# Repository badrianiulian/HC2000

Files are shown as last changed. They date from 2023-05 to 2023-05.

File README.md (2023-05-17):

# HC2000

## Note în limba română
Proiect de reconstrucție HC2000

Ce s-a folosit pentru a crea acest proiect:
- Versiunea originală a schemei HC-2000 Rev B care a fost obținută prin intermediul grupului Romanian Home Computer (mulțumiri speciale domnului George Chirtoacă)
- Schema Eagle a HC-2000 Rev B realizată de dl. Liviu Grama, care este de asemenea membru al grupului Romanian Home Computer
- Un exemplar fizic al unui HC-2000 Rev E furnizat de dl. Oică Cezar pentru reparații

Note despre diferențe:
- HC2000_ORIGINAL este proiectul realizat folosind scanările cablajului exemplarului fizic HC-2000 Rev E
- gerberele au fost create folosind proiectul HC2000, care este Rev E modificată pentru a include firele lipite peste cablaj
- observați că unele componente au două valori precum R28, R40 și R41 egale cu 220/1K: prima valoare 220 este pentru Rev B și a doua valoare 1K este pentru Rev E
- unde se întâlnește un "-", înseamnă că acea componentă lipsește pe cablajul Rev E, dar locul de amplasare al componentei este disponibil
- pentru conectorul de alimentare am adăugat pe lângă locul de amplasare al conectorului original, un conector cu 6 pini DIN

**IMPORTANT**: În prima revizie a proiectului s-au strecurat câteva greșeli:
- Nu am observat o tăietură pe placa originală ceea ce a dus la unirea a două trasee. Această secțiune este documentată pe grupul Romanian Home Computer de Radioman V: https://groups.google.com/g/romanianhomecomputer/c/qHbKBThCIQc/m/c_SBp--mCgAJ
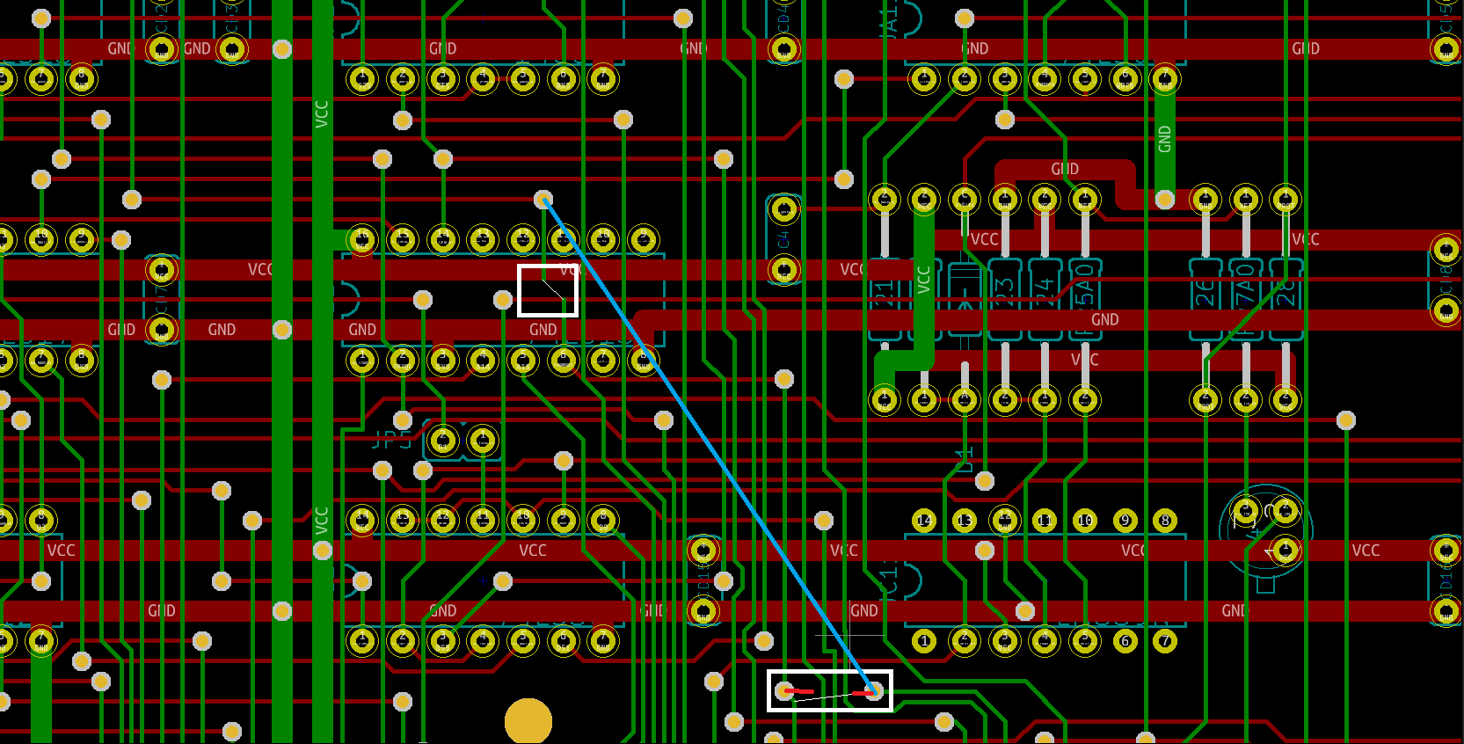
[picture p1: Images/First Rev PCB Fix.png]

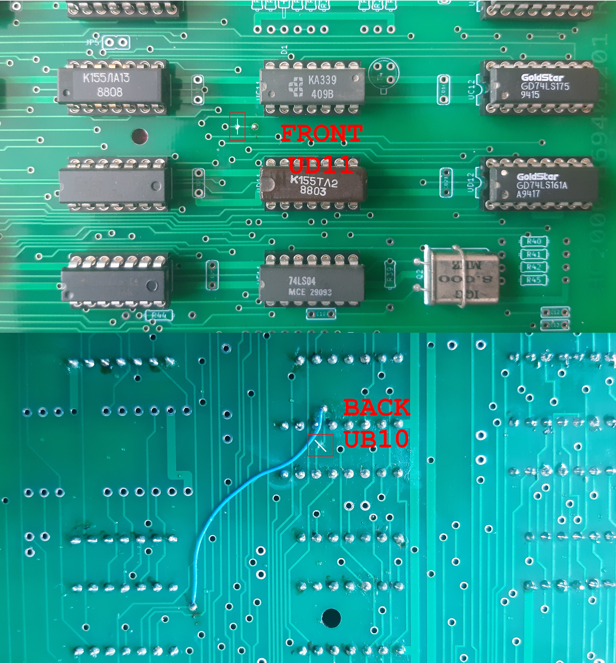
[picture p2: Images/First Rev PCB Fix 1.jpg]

- Au rămas două circuite cu titulatura veche de pe proiectul original care a fost convertit
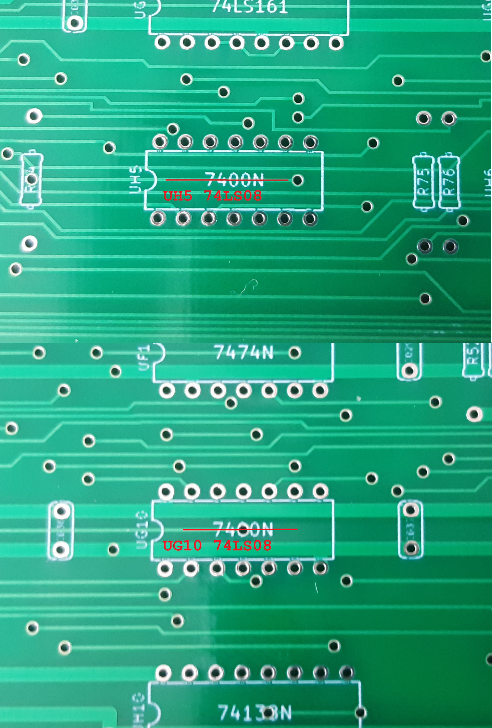
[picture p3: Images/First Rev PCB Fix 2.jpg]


## English notes
HC2000 rebuild project

What was used to create this project:
- Original version of the schematic of HC-2000 Rev B that was obtained through the Romanian Home Computer group (special thanks to mr. George Chirtoacă)
- Eagle schematic of the HC-2000 Rev B made by mr. Liviu Grama also a member of the Romanian Home Computer group
- A physical HC-2000 Rev E provided by mr. Oică Cezar for repairs

Notes on the diferences:
- HC2000_ORIGINAL is the project made using PCB scans of the physical HC-2000 Rev E
- gerbers were created using HC2000 project witch is the modified Rev E witch includes the over-the-PCB soldered wires
- notice some components have two values like R28, R40 and R41 equal 220/1K: first value 220 is for Rev B and second value 1K is for Rev E
- where a "-" is encountered, it means that the component is missing on Rev E but the footprint is available
- for the power connector I added side by side with the original connector's footprint, a 6-pin DIN connector

**IMPORTANT**: In the original project a few mistakes slipped in.
- I did not notice a cut on the original PCB witch led to joining of two tracks. This section is documented on the Romanian Home Computer group by Radioman V: https://groups.google.com/g/romanianhomecomputer/c/qHbKBThCIQc/m/c_SBp--mCgAJ


- Two circuits retained the old names from the original converted project


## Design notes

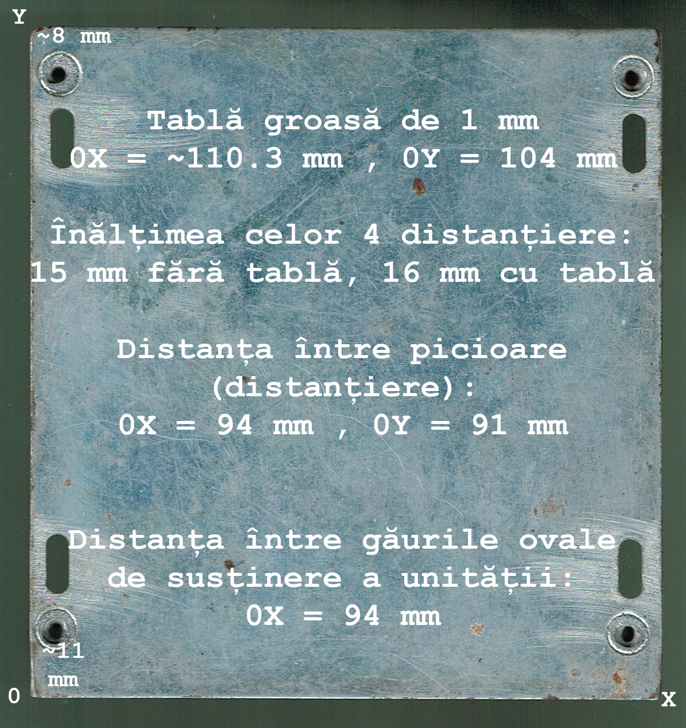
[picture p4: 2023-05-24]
Other/Floppy_Stand.jpg

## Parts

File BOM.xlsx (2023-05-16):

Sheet: ListaOriginală
Collated Components:
Item | Qty | Reference(s) | Value | LibPart | Footprint | Datasheet | DNP | Sim.Device | Sim.Pins
1 | 2 | C1, C3 | 100n | HC2000:C-EU025-025X050 | HC2000:C025-030X050
2 | 1 | C2 | 4n7 | HC2000:C-EU025-030X050 | HC2000:C025-030X050
3 | 1 | C4 | 3,3uF/4,7uF | HC2000:CPOL-EU140CLH-0810 | HC2000:C025-024X044
4 | 1 | C5 | 270p | HC2000:C-EU025-030X050 | HC2000:C025-030X050
5 | 1 | C6 | 150p | HC2000:C-EU025-025X050 | HC2000:C025-030X050
6 | 1 | C7 | 10p/15p | HC2000:C-EU025-025X050 | HC2000:C025-030X050
7 | 1 | C8 | 220p/- | HC2000:C-EU025-025X050 | HC2000:C025-030X050
8 | 1 | C9 | 220p | HC2000:C-EU025-025X050 | HC2000:C025-030X050
9 | 1 | C10 | 270p | HC2000:C-EU025-024X044 | HC2000:C025-025X050
10 | 1 | C11 | 270p | HC2000:C-EU025-030X050 | HC2000:C025-025X050
11 | 4 | C12, C13, C16, C17 | 4n7 | HC2000:C-EU025-025X050 | HC2000:C025-025X050
12 | 1 | C14 | 100p/180p | HC2000:C-EU025-025X050 | HC2000:C025-030X050
13 | 1 | C15 | 10u | HC2000:CPOL-EU140CLH-1010 | HC2000:C025-024X024
14 | 7 | CD1, CD6, CD22, CD36, CD37, CD39, CD40 | u1 | :C-EU025-024X044_4 | HC2000:C025-024X044
15 | 5 | CD2, CD4, CD7, CD8, CD38 | - | :C-EU025-024X044_4 | HC2000:C025-024X044
16 | 2 | CD3, CD5 | 100u | :C-EU025-024X044_4 | HC2000:C025-024X044
17 | 1 | CD9 | u1 | :C-EU025-024X044_10 | HC2000:C025-024X044
18 | 1 | CD10 | - | :C-EU025-024X044_11 | HC2000:C025-024X044
19 | 1 | CD11 | u1 | :C-EU025-024X044_11 | HC2000:C025-024X044
20 | 1 | CD12 | 100u | :C-EU025-024X044_12 | HC2000:C025-024X044
21 | 1 | CD13 | u1 | :C-EU025-024X044_15 | HC2000:C025-024X044
22 | 1 | CD14 | - | :C-EU025-024X044_14 | HC2000:C025-024X044
23 | 1 | CD15 | u1 | :C-EU025-024X044_16 | HC2000:C025-024X044
24 | 9 | CD16, CD17, CD24, CD25, CD26, CD27, CD31, CD32, CD33 | u1 | :C-EU025-024X044_13 | HC2000:C025-024X044
25 | 1 | CD18 | 100u | :C-EU025-024X044_13 | HC2000:C025-024X044
26 | 1 | CD19 | u1 | HC2000:C-EU025-024X044 | HC2000:C025-024X044
27 | 1 | CD20 | u1 | :C-EU025-024X044_17 | HC2000:C025-024X044
28 | 1 | CD21 | u1 | :C-EU025-024X044_5 | HC2000:C025-024X044
29 | 1 | CD23 | 100u | :C-EU025-024X044_8 | HC2000:C025-024X044
30 | 1 | CD28 | - | :C-EU025-024X044_1 | HC2000:C025-024X044
31 | 1 | CD29 | - | :C-EU025-024X044_3 | HC2000:C025-024X044
32 | 1 | CD30 | u1 | :C-EU025-024X044_2 | HC2000:C025-024X044
33 | 1 | CD34 | - | :C-EU025-024X044_13 | HC2000:C025-024X044
34 | 1 | CD35 | u1 | :C-EU025-024X044_6 | HC2000:C025-024X044
35 | 1 | CT0 | 10-60pF | HC2000:C-TRIMM808 | HC2000:CTRIM808-BC
36 | 1 | CX0 | 100u | HC2000:CPOL-EU140CLH-0810 | HC2000:C025-024X044
37 | 1 | CY1 | 1.5u | HC2000:CPOL-EU140CLH-1010 | HC2000:140CLH-1010
38 | 8 | D1, D2, D3, D4, D5, D6, D7, D8 | 1N4148 | HC2000:1N4148DO35-10 | HC2000:DO35-10
39 | 1 | DX1 | 1N4148 | HC2000:1N4148DO35-7 | HC2000:DO35-7 | https://assets.nexperia.com/documents/data-sheet/1N4148_1N4448.pdf |  | D | 1=K 2=A
40 | 1 | J1 | VIDEO | HC2000:F09FD | HC2000:DSUB-9_Female_Horizontal_P2.77x2.84mm_EdgePinOffset7.70mm_Housed_MountingHolesOffset9.12mm
41 | 1 | J2 | JOYSTICK | HC2000:F09MD | HC2000:DSUB-9_Male_Horizontal_P2.77x2.84mm_EdgePinOffset7.70mm_Housed_MountingHolesOffset9.12mm
42 | 1 | J3 | MAB5SH | HC2000:MAB5SH | HC2000:MAB5SH
43 | 2 | J4, J6 | . | HC2000:HC-POWER | HC2000:HC-POWER
44 | 1 | J5 | RS232 + RETEA | HC2000:F09FD | HC2000:DSUB-9_Female_Horizontal_P2.77x2.84mm_EdgePinOffset7.70mm_Housed_MountingHolesOffset9.12mm
45 | 2 | J7, J8 | FDD-CON | HC2000:PINHD-2X17 | HC2000:2X17
46 | 1 | J9 | . | HC2000:MTA04-100 | HC2000:10X04MTA
47 | 1 | J10 | SDS-60J | HC2000:SDS-60J | HC2000:SDS-60J-CUI_SDS-60J
48 | 2 | JP2, JP5 | - | HC2000:JP1E | HC2000:JP1
49 | 1 | KB-CONN0 | DIP16 | HC2000:DIL16 | HC2000:DIL16
50 | 1 | L1 | 100 | HC2000:L-USPIS2816 | HC2000:PIS2816
51 | 1 | Q1 | 17,734 | HC2000:CRYSTALHC18U-H | HC2000:HC18U-H
52 | 1 | Q2 | 8MHz | HC2000:CRYSTALHC18U-H | HC2000:HC18U-H
53 | 24 | R1, R2, R3, R4, R13, R14, R34, R37, R38, R44, R47, R49, R51, R53, R55, R58, R63, R72, R73, R74, R75, R76, R77, R78 | 1k | HC2000:R-EU_0204{slash}7 | HC2000:0204_7
54 | 2 | R5, R60 | 330/300 | HC2000:R-EU_0204{slash}7 | HC2000:0204_7
55 | 1 | R6 | 2M2/2M | HC2000:R-EU_0204{slash}7 | HC2000:0204_7
56 | 11 | R7, R8, R9, R11, R15, R16, R18, R20, R25A0, R29, R52 | 10k | HC2000:R-EU_0204{slash}7 | HC2000:0204_7
57 | 1 | R10 | 47k | HC2000:R-EU_0204{slash}7 | HC2000:0204_7
58 | 2 | R12, R17 | 2k | HC2000:R-EU_0204{slash}7 | HC2000:0204_7
59 | 5 | R19, R19B0, R33, R43, R50A0 | 470 | HC2000:R-EU_0204{slash}7 | HC2000:0204_7
60 | 1 | R21 | 10k/470k | HC2000:R-EU_0204{slash}7 | HC2000:0204_7
61 | 1 | R22 | 8k2/6k | HC2000:R-EU_0204{slash}7 | HC2000:0204_7
62 | 1 | R23 | 220 | HC2000:R-EU_0204{slash}7 | HC2000:0204_7
63 | 1 | R24 | 430 | HC2000:R-EU_0204{slash}7 | HC2000:0204_7
64 | 3 | R26, R42, R45 | 330/- | HC2000:R-EU_0204{slash}7 | HC2000:0204_7
65 | 1 | R27A0 | 47 | HC2000:R-EU_0204{slash}7 | HC2000:0204_7
66 | 4 | R28, R40, R41, R56 | 220/1k | HC2000:R-EU_0204{slash}7 | HC2000:0204_7
67 | 2 | R30, R48 | 75/69 | HC2000:R-EU_0204{slash}7 | HC2000:0204_7
68 | 1 | R31 | 240/270 | HC2000:R-EU_0204{slash}7 | HC2000:0204_7
69 | 1 | R32 | 1k5 | HC2000:R-EU_0204{slash}7 | HC2000:0204_7
70 | 1 | R35 | 680 | HC2000:R-EU_0204{slash}7 | HC2000:0204_7
71 | 1 | R36 | 100 | HC2000:R-EU_0204{slash}7 | HC2000:0204_7
72 | 3 | R39, R46, R57 | 560 | HC2000:R-EU_0204{slash}7 | HC2000:0204_7
73 | 2 | R54, R61 | 3k9 | HC2000:R-EU_0204{slash}7 | HC2000:0204_7
74 | 1 | R59 | 27k | HC2000:R-EU_0204{slash}7 | HC2000:0204_7
75 | 2 | R62, R67 | 910 | HC2000:R-EU_0204{slash}7 | HC2000:0204_7
76 | 1 | R64 | 7k5 | HC2000:R-EU_0204{slash}7 | HC2000:0204_7
77 | 2 | R65, R71 | 510 | HC2000:R-EU_0204{slash}7 | HC2000:0204_7
78 | 1 | R66 | 1k8/1k6 | HC2000:R-EU_0204{slash}7 | HC2000:0204_7
79 | 1 | R68 | 5k6/5k1 | HC2000:R-EU_0204{slash}7 | HC2000:0204_7
80 | 1 | R69 | 2k7 | HC2000:R-EU_0204{slash}7 | HC2000:0204_7
81 | 1 | R70 | 1k1 | HC2000:R-EU_0204{slash}7 | HC2000:0204_7
82 | 1 | RP1 | 10k | HC2000:G08R | HC2000:SIL9
83 | 1 | SPEAKER0 | BEL | HC2000:AL11P | HC2000:AL11P
84 | 1 | SW1 | RESET_SW | HC2000:RESET_SW | HC2000:RESET_SW | ~
85 | 1 | T1 | BD139 | HC2000:BD139 | HC2000:TO-126-3_Vertical
86 | 1 | T2 | 2N2369/2N2368 | HC2000:2N2369 | HC2000:TO18
87 | 1 | T3 | 2N2369/BC108A | HC2000:2N2369 | HC2000:TO18
88 | 2 | T4, T5 | BC177 | HC2000:BC177 | HC2000:TO18
89 | 2 | UA1, UC7 | 74244N | HC2000:74244N | HC2000:DIL20
90 | 1 | UA7 | LM324N | HC2000:LM324N | HC2000:DIL14
91 | 2 | UA8, UC8 | 2k x 4bit/- | HC2000:2114 | HC2000:DIL18
92 | 5 | UA9, UB10, UE4, UF8, UH10 | 74138N | HC2000:74138N | HC2000:DIL16
93 | 1 | UA10 | 1488 | HC2000:DIL14 | HC2000:DIL14
94 | 1 | UA11 | 7406N | HC2000:7406N | HC2000:DIL14
95 | 1 | UA12 | NE555 | HC2000:NE555 | HC2000:DIL-08
96 | 2 | UA23, UA34 | 7409N | HC2000:7409N | HC2000:DIL14
97 | 8 | UB1, UD3, UD10, UE10, UF4, UF10, UG12, UH12 | 7474N | HC2000:7474N | HC2000:DIL14
98 | 4 | UB2, UG10, UH3, UH5 | 7400N | HC2000:7400N | HC2000:DIL14
99 | 1 | UB3 | 74367N | HC2000:74367N | HC2000:DIL16
100 | 1 | UB6 | 27C256/27C512 | HC2000:27256 | HC2000:DIL28
101 | 2 | UB9, UF7 | 74174N | HC2000:74174N | HC2000:DIL16
102 | 1 | UB12 | 74153N | HC2000:74153N | HC2000:DIL16
103 | 1 | UB45 | Z80 - CPU | HC2000:Z80CPU | HC2000:DIL40
104 | 4 | UC1, UE11, UG0, UG4 | 7404N | HC2000:7404N | HC2000:DIL14
105 | 1 | UC2 | 7427N | HC2000:7427N | HC2000:DIL14
106 | 5 | UC3, UE3, UF9, UG9, UH8 | 7432N | HC2000:7432N | HC2000:DIL14
107 | 5 | UC4, UC5, UD5, UG7, UH6 | 74257N | HC2000:74257N | HC2000:DIL16
108 | 1 | UC6 | 74373N | HC2000:74373N | HC2000:DIL20
109 | 1 | UC9 | 74125N | HC2000:74125N | HC2000:DIL14
110 | 1 | UC10 | 74LS38N | HC2000:7403N | HC2000:DIL14
111 | 1 | UC11 | LM339N | HC2000:LM339N | HC2000:DIL14
112 | 4 | UC12, UF3, UG3, UH1 | 74175N | HC2000:74175N | HC2000:DIL16
113 | 3 | UD1, UE2, UG11 | 7408N | HC2000:7408N | HC2000:DIL14
114 | 1 | UD4 | 74157N | HC2000:74157N | HC2000:DIL16
115 | 3 | UD6, UF6, UG6 | 74374N | HC2000:74374N | HC2000:DIL20
116 | 2 | UD7, UE7 | 41464 | HC2000:41464C | HC2000:DIL18
117 | 1 | UD11 | 7414N | HC2000:7414N | HC2000:DIL14
118 | 1 | UD12 | 74LS161N | HC2000:4161P | HC2000:DIL16
119 | 5 | UE5, UF2, UF5, UG5, UH7 | 74LS161 | HC2000:4161P | HC2000:DIL16
120 | 1 | UE6 | 74166N | HC2000:74166N | HC2000:DIL16
121 | 1 | UE8 | 8272 | HC2000:8272 | HC2000:DIL40
122 | 1 | UE8A0 | 27128P/- | HC2000:27128P | HC2000:DIL28-6
123 | 1 | UF12 | 1489 | HC2000:DIL14 | HC2000:DIL14
124 | 1 | UG1 | 7442N | HC2000:7442N | HC2000:DIL16
125 | 1 | UG2 | 82S128 | HC2000:DIL16 | HC2000:DIL16
126 | 1 | UG8 | 7405N | HC2000:7405N | HC2000:DIL14
127 | 1 | UGX1 | PROM ALT - W27C256-45 | HC2000:27256 | HC2000:DIL28
128 | 1 | UH4 | 7486N | HC2000:7486N | HC2000:DIL14
129 | 1 | UH11 | 7493N | HC2000:7493N | HC2000:DIL14
130 | 1 | UX1 | UM6116-3 | HC2000:6116 | HC2000:DIL24
131 | 1 | UX2 | LM555M | HC2000:LM555M | HC2000:DIL14
132 | 1 | Z1 | HCBUS | HC2000:HCBUS | HC2000:HC_Bus_Edge_Connector

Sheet: Mărunțișuri
Collated Components:
Item | Qty | Reference(s) | Value | LibPart | Footprint | Datasheet | DNP | Sim.Device | Sim.Pins
1 | 2 | C1, C3 | 100n | HC2000:C-EU025-025X050 | HC2000:C025-030X050
2 | 1 | C2 | 4n7 | HC2000:C-EU025-030X050 | HC2000:C025-030X050
3 | 1 | C4 | 3,3uF/4,7uF | HC2000:CPOL-EU140CLH-0810 | HC2000:C025-024X044
4 | 1 | C5 | 270p | HC2000:C-EU025-030X050 | HC2000:C025-030X050
5 | 1 | C6 | 150p | HC2000:C-EU025-025X050 | HC2000:C025-030X050
6 | 1 | C7 | 10p/15p | HC2000:C-EU025-025X050 | HC2000:C025-030X050
7 | 1 | C8 | 220p/- | HC2000:C-EU025-025X050 | HC2000:C025-030X050
8 | 1 | C9 | 220p | HC2000:C-EU025-025X050 | HC2000:C025-030X050
9 | 1 | C10 | 270p | HC2000:C-EU025-024X044 | HC2000:C025-025X050
10 | 1 | C11 | 270p | HC2000:C-EU025-030X050 | HC2000:C025-025X050
11 | 4 | C12, C13, C16, C17 | 4n7 | HC2000:C-EU025-025X050 | HC2000:C025-025X050
12 | 1 | C14 | 100p/180p | HC2000:C-EU025-025X050 | HC2000:C025-030X050
13 | 1 | C15 | 10u | HC2000:CPOL-EU140CLH-1010 | HC2000:C025-024X024
14 | 7 | CD1, CD6, CD22, CD36, CD37, CD39, CD40 | u1 | :C-EU025-024X044_4 | HC2000:C025-024X044
15 | 5 | CD2, CD4, CD7, CD8, CD38 | - | :C-EU025-024X044_4 | HC2000:C025-024X044
16 | 2 | CD3, CD5 | 100u | :C-EU025-024X044_4 | HC2000:C025-024X044
17 | 1 | CD9 | u1 | :C-EU025-024X044_10 | HC2000:C025-024X044
18 | 1 | CD10 | - | :C-EU025-024X044_11 | HC2000:C025-024X044
19 | 1 | CD11 | u1 | :C-EU025-024X044_11 | HC2000:C025-024X044
20 | 1 | CD12 | 100u | :C-EU025-024X044_12 | HC2000:C025-024X044
21 | 1 | CD13 | u1 | :C-EU025-024X044_15 | HC2000:C025-024X044
22 | 1 | CD14 | - | :C-EU025-024X044_14 | HC2000:C025-024X044
23 | 1 | CD15 | u1 | :C-EU025-024X044_16 | HC2000:C025-024X044
24 | 9 | CD16, CD17, CD24, CD25, CD26, CD27, CD31, CD32, CD33 | u1 | :C-EU025-024X044_13 | HC2000:C025-024X044
25 | 1 | CD18 | 100u | :C-EU025-024X044_13 | HC2000:C025-024X044
26 | 1 | CD19 | u1 | HC2000:C-EU025-024X044 | HC2000:C025-024X044
27 | 1 | CD20 | u1 | :C-EU025-024X044_17 | HC2000:C025-024X044
28 | 1 | CD21 | u1 | :C-EU025-024X044_5 | HC2000:C025-024X044
29 | 1 | CD23 | 100u | :C-EU025-024X044_8 | HC2000:C025-024X044
30 | 1 | CD28 | - | :C-EU025-024X044_1 | HC2000:C025-024X044
31 | 1 | CD29 | - | :C-EU025-024X044_3 | HC2000:C025-024X044
32 | 1 | CD30 | u1 | :C-EU025-024X044_2 | HC2000:C025-024X044
33 | 1 | CD34 | - | :C-EU025-024X044_13 | HC2000:C025-024X044
34 | 1 | CD35 | u1 | :C-EU025-024X044_6 | HC2000:C025-024X044
35 | 1 | CT0 | 10-60pF | HC2000:C-TRIMM808 | HC2000:CTRIM808-BC
36 | 1 | CX0 | 100u | HC2000:CPOL-EU140CLH-0810 | HC2000:C025-024X044
37 | 1 | CY1 | 1.5u | HC2000:CPOL-EU140CLH-1010 | HC2000:140CLH-1010
38 | 8 | D1, D2, D3, D4, D5, D6, D7, D8 | 1N4148 | HC2000:1N4148DO35-10 | HC2000:DO35-10
39 | 1 | DX1 | 1N4148 | HC2000:1N4148DO35-7 | HC2000:DO35-7 | https://assets.nexperia.com/documents/data-sheet/1N4148_1N4448.pdf |  | D | 1=K 2=A
40 | 1 | J1 | VIDEO | HC2000:F09FD | HC2000:DSUB-9_Female_Horizontal_P2.77x2.84mm_EdgePinOffset7.70mm_Housed_MountingHolesOffset9.12mm
41 | 1 | J2 | JOYSTICK | HC2000:F09MD | HC2000:DSUB-9_Male_Horizontal_P2.77x2.84mm_EdgePinOffset7.70mm_Housed_MountingHolesOffset9.12mm
42 | 1 | J3 | MAB5SH | HC2000:MAB5SH | HC2000:MAB5SH
43 | 2 | J4, J6 | . | HC2000:HC-POWER | HC2000:HC-POWER
44 | 1 | J5 | RS232 + RETEA | HC2000:F09FD | HC2000:DSUB-9_Female_Horizontal_P2.77x2.84mm_EdgePinOffset7.70mm_Housed_MountingHolesOffset9.12mm
45 | 2 | J7, J8 | FDD-CON | HC2000:PINHD-2X17 | HC2000:2X17
46 | 1 | J9 | . | HC2000:MTA04-100 | HC2000:10X04MTA
47 | 1 | J10 | SDS-60J | HC2000:SDS-60J | HC2000:SDS-60J-CUI_SDS-60J
48 | 2 | JP2, JP5 | - | HC2000:JP1E | HC2000:JP1
49 | 1 | KB-CONN0 | DIP16 | HC2000:DIL16 | HC2000:DIL16
50 | 1 | L1 | 100 | HC2000:L-USPIS2816 | HC2000:PIS2816
51 | 1 | Q1 | 17,734 | HC2000:CRYSTALHC18U-H | HC2000:HC18U-H
52 | 1 | Q2 | 8MHz | HC2000:CRYSTALHC18U-H | HC2000:HC18U-H
53 | 24 | R1, R2, R3, R4, R13, R14, R34, R37, R38, R44, R47, R49, R51, R53, R55, R58, R63, R72, R73, R74, R75, R76, R77, R78 | 1k | HC2000:R-EU_0204{slash}7 | HC2000:0204_7
54 | 2 | R5, R60 | 330/300 | HC2000:R-EU_0204{slash}7 | HC2000:0204_7
55 | 1 | R6 | 2M2/2M | HC2000:R-EU_0204{slash}7 | HC2000:0204_7
56 | 11 | R7, R8, R9, R11, R15, R16, R18, R20, R25A0, R29, R52 | 10k | HC2000:R-EU_0204{slash}7 | HC2000:0204_7
57 | 1 | R10 | 47k | HC2000:R-EU_0204{slash}7 | HC2000:0204_7
58 | 2 | R12, R17 | 2k | HC2000:R-EU_0204{slash}7 | HC2000:0204_7
59 | 5 | R19, R19B0, R33, R43, R50A0 | 470 | HC2000:R-EU_0204{slash}7 | HC2000:0204_7
60 | 1 | R21 | 10k/470k | HC2000:R-EU_0204{slash}7 | HC2000:0204_7
61 | 1 | R22 | 8k2/6k | HC2000:R-EU_0204{slash}7 | HC2000:0204_7
62 | 1 | R23 | 220 | HC2000:R-EU_0204{slash}7 | HC2000:0204_7
63 | 1 | R24 | 430 | HC2000:R-EU_0204{slash}7 | HC2000:0204_7
64 | 3 | R26, R42, R45 | 330/- | HC2000:R-EU_0204{slash}7 | HC2000:0204_7
65 | 1 | R27A0 | 47 | HC2000:R-EU_0204{slash}7 | HC2000:0204_7
66 | 4 | R28, R40, R41, R56 | 220/1k | HC2000:R-EU_0204{slash}7 | HC2000:0204_7
67 | 2 | R30, R48 | 75/69 | HC2000:R-EU_0204{slash}7 | HC2000:0204_7
68 | 1 | R31 | 240/270 | HC2000:R-EU_0204{slash}7 | HC2000:0204_7
69 | 1 | R32 | 1k5 | HC2000:R-EU_0204{slash}7 | HC2000:0204_7
70 | 1 | R35 | 680 | HC2000:R-EU_0204{slash}7 | HC2000:0204_7
71 | 1 | R36 | 100 | HC2000:R-EU_0204{slash}7 | HC2000:0204_7
72 | 3 | R39, R46, R57 | 560 | HC2000:R-EU_0204{slash}7 | HC2000:0204_7
73 | 2 | R54, R61 | 3k9 | HC2000:R-EU_0204{slash}7 | HC2000:0204_7
74 | 1 | R59 | 27k | HC2000:R-EU_0204{slash}7 | HC2000:0204_7
75 | 2 | R62, R67 | 910 | HC2000:R-EU_0204{slash}7 | HC2000:0204_7
76 | 1 | R64 | 7k5 | HC2000:R-EU_0204{slash}7 | HC2000:0204_7
77 | 2 | R65, R71 | 510 | HC2000:R-EU_0204{slash}7 | HC2000:0204_7
78 | 1 | R66 | 1k8/1k6 | HC2000:R-EU_0204{slash}7 | HC2000:0204_7
79 | 1 | R68 | 5k6/5k1 | HC2000:R-EU_0204{slash}7 | HC2000:0204_7
80 | 1 | R69 | 2k7 | HC2000:R-EU_0204{slash}7 | HC2000:0204_7
81 | 1 | R70 | 1k1 | HC2000:R-EU_0204{slash}7 | HC2000:0204_7
82 | 1 | RP1 | 10k | HC2000:G08R | HC2000:SIL9
83 | 1 | SPEAKER0 | BEL | HC2000:AL11P | HC2000:AL11P
84 | 1 | SW1 | RESET_SW | HC2000:RESET_SW | HC2000:RESET_SW | ~

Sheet: Tranzistoare
Collated Components:
Item | Qty | Reference(s) | Value | LibPart | Footprint | Datasheet | DNP | Sim.Device | Sim.Pins
85 | 1 | T1 | BD139 | HC2000:BD139 | HC2000:TO-126-3_Vertical
86 | 1 | T2 | 2N2369/2N2368 | HC2000:2N2369 | HC2000:TO18
87 | 1 | T3 | 2N2369/BC108A | HC2000:2N2369 | HC2000:TO18
88 | 2 | T4, T5 | BC177 | HC2000:BC177 | HC2000:TO18

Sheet: Circuite
Collated Components:
Item | Qty | Reference(s) | Value | Qty | Reference(s) | Rev E |  | LibPart | Footprint | Datasheet | DNP | Sim.Device | Sim.Pins
93 | 1 | UA10 | 1488 | 1 | UA10 | 1488 |  | HC2000:DIL14 | HC2000:DIL14
123 | 1 | UF12 | 1489 | 1 | UF12 | 1489 |  | HC2000:DIL14 | HC2000:DIL14
100 | 1 | UB6 | 27C512 | 1 | UB6 | 27C512 | Am W27C512-70 care ar trebui să meargă | HC2000:27256 | HC2000:DIL28
98 | 2 | UB2, UH3 | 7400N | 2 | UB2, UH3 | 74LS00 |  | HC2000:7400N | HC2000:DIL14
104 | 4 | UC1, UE11, UG0, UG4 | 7404N | 4 | UC1, UE11, UG0, UG4 | 74LS04 | Merg Beta 7404? Am mai multe | HC2000:7404N | HC2000:DIL14
126 | 1 | UG8 | 7405N | 1 | UG8 | 74LS05 = К555ЛН2 |  | HC2000:7405N | HC2000:DIL14
94 | 1 | UA11 | 7406N | 1 | UA11 | 74LS06 |  | HC2000:7406N | HC2000:DIL14
113 | 5 | UD1, UE2, UG10, UG11, UH5 | 7408N | 5 | UD1, UE2, UG10, UG11, UH5 | 74LS08 |  | HC2000:7408N | HC2000:DIL14
96 | 2 | UA23, UA34 | 7409N | 2 | UA23, UA34 | 74LS09 |  | HC2000:7409N | HC2000:DIL14
109 | 1 | UC9 | 74125N | 1 | UC9 | 74LS125A |  | HC2000:74125N | HC2000:DIL14
92 | 5 | UA9, UB10, UE4, UF8, UH10 | 74138N | 5 | UA9, UB10, UE4, UF8, UH10 | 74LS138 |  | HC2000:74138N | HC2000:DIL16
117 | 1 | UD11 | 7414N | 1 | UD11 | 74LS14 = К155ТЛ2 |  | HC2000:7414N | HC2000:DIL14
102 | 1 | UB12 | 74153N | 1 | UB12 | 74LS153 |  | HC2000:74153N | HC2000:DIL16
114 | 1 | UD4 | 74157N | 1 | UD4 | 74LS157 |  | HC2000:74157N | HC2000:DIL16
119 | 6 | UD12, UE5, UF2, UF5, UG5, UH7 | 74LS161 | 6 | UD12, UE5, UF2, UF5, UG5, UH7 | 74LS161A |  | HC2000:4161P | HC2000:DIL16
120 | 1 | UE6 | 74166N | 1 | UE6 | 74LS166 |  | HC2000:74166N | HC2000:DIL16
101 | 2 | UB9, UF7 | 74174N | 2 | UB9, UF7 | 74LS174 = К555ТМ9 |  | HC2000:74174N | HC2000:DIL16
112 | 4 | UC12, UF3, UG3, UH1 | 74175N | 4 | UC12, UF3, UG3, UH1 | 74LS175 |  | HC2000:74175N | HC2000:DIL16
89 | 2 | UA1, UC7 | 74244N | 2 | UA1, UC7 | 74LS244 = К1533АП5 |  | HC2000:74244N | HC2000:DIL20
107 | 5 | UC4, UC5, UD5, UG7, UH6 | 74257N | 5 | UC4, UC5, UD5, UG7, UH6 | 74LS257A |  | HC2000:74257N | HC2000:DIL16
105 | 1 | UC2 | 7427N | 1 | UC2 | 74LS27 |  | HC2000:7427N | HC2000:DIL14
106 | 5 | UC3, UE3, UF9, UG9, UH8 | 7432N | 5 | UC3, UE3, UF9, UG9, UH8 | 74LS32 |  | HC2000:7432N | HC2000:DIL14
99 | 1 | UB3 | 74367N | 1 | UB3 | 74LS367AN |  | HC2000:74367N | HC2000:DIL16
108 | 1 | UC6 | 74373N | 1 | UC6 | 74LS373 |  | HC2000:74373N | HC2000:DIL20
115 | 3 | UD6, UF6, UG6 | 74374N | 3 | UD6, UF6, UG6 | 74LS374B1 |  | HC2000:74374N | HC2000:DIL20
110 | 1 | UC10 | 74LS38N | 1 | UC10 | 74LS38N | Am | HC2000:7403N | HC2000:DIL14
124 | 1 | UG1 | 7442N | 1 | UG1 | 74LS442 |  | HC2000:7442N | HC2000:DIL16
97 | 8 | UB1, UD3, UD10, UE10, UF4, UF10, UG12, UH12 | 7474N | 8 | UB1, UD3, UD10, UE10, UF4, UF10, UG12, UH12 | 74LS74A | Am vreo 10 comandate din China | HC2000:7474N | HC2000:DIL14
128 | 1 | UH4 | 7486N | 1 | UH4 | 74LS86 |  | HC2000:7486N | HC2000:DIL14
129 | 1 | UH11 | 7493N | 1 | UH11 | 74LS93 = DL093D |  | HC2000:7493N | HC2000:DIL14
121 | 1 | UE8 | 8272 | 1 | UE8 | D765AC-2 |  | HC2000:8272 | HC2000:DIL40
111 | 1 | UC11 | LM339N | 1 | UC11 | KA339 |  | HC2000:LM339N | HC2000:DIL14
90 | 1 | UA7 | LM324N | 1 | UA7 | KIA324P | Am | HC2000:LM324N | HC2000:DIL14
95 | 1 | UA12 | NE555 | 1 | UA12 | NE555 |  | HC2000:NE555 | HC2000:DIL-08
116 | 2 | UD7, UE7 | 41464 | 2 | UD7, UE7 | TMM41464AP-12 |  | HC2000:41464C | HC2000:DIL18
130 | 1 | UX1 | UM6116-3 | 1 | UX1 | UM6116-3 |  | HC2000:6116 | HC2000:DIL24
103 | 1 | UB45 | Z80 - CPU | 1 | UB45 | Z80A | Am niște Sharp-uri LH0080A Z80A-CPU-D | HC2000:Z80CPU | HC2000:DIL40
125 | 1 | UG2 | 82S128 | 1 | UG2 | КР556РТ1 | Ovidiu a oferit un PROM din colecție deja programat | HC2000:DIL16 | HC2000:DIL16
 |  |  |  | 1 | RP1 | 10k | Aș putea face o invenție dar poate găsesc ceva original
 |  |  |  | 1 | L1 | 100
 |  |  |  | 1 | Q1 | 17,734
 |  |  |  | 1 | Q2 | 8MHz | Mai am o cutie în care nu am căutat

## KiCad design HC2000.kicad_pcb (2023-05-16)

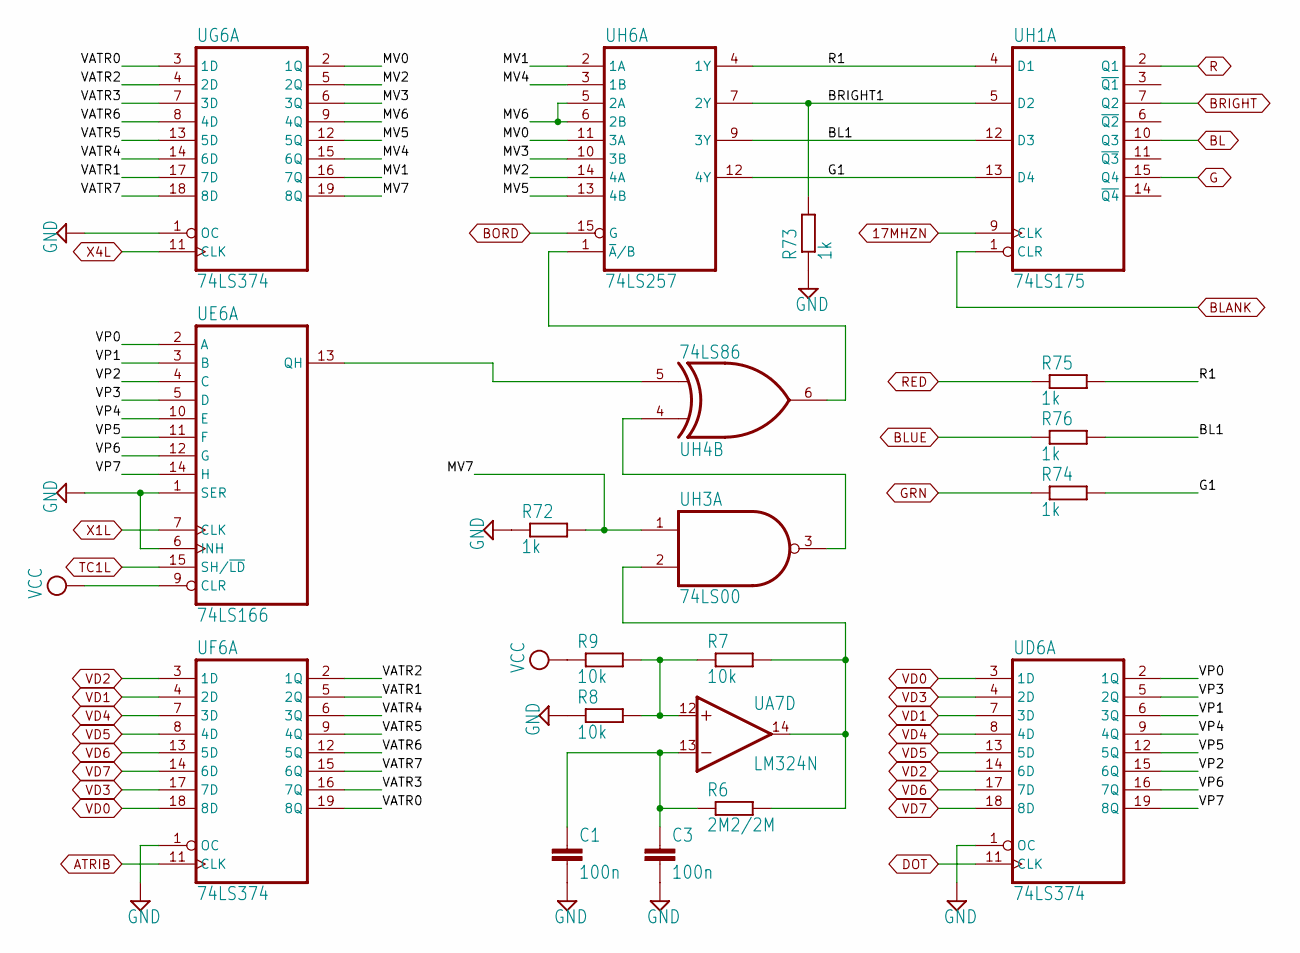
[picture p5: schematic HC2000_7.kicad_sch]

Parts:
C1, C3: 100n; C025-030X050
R6: 2M2/2M; 0204_7
R7, R8, R9: 10k; 0204_7
R72, R73, R74, R75, R76: 1k; 0204_7
UA7: LM324N; DIL14
UD6: 74LS374; DIL20
UE6: 74LS166; DIL16
UF6: 74LS374; DIL20
UG6: 74LS374; DIL20
UH1: 74LS175; DIL16
UH3: 74LS00; DIL14
UH4: 74LS86; DIL14
UH6: 74LS257; DIL16

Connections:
17MHZN: UH1.9 (CLK); also elsewhere on the board
/HC2000_7/BL1: R76.2, UH1.12 (D3), UH6.9 (3Y)
/HC2000_7/BRIGHT1: R73.2, UH1.5 (D2), UH6.7 (2Y)
/HC2000_7/G1: R74.2, UH1.13 (D4), UH6.12 (4Y)
/HC2000_7/MV0: UG6.2 (1Q), UH6.11 (3A)
/HC2000_7/MV1: UG6.16 (7Q), UH6.2 (1A)
/HC2000_7/MV2: UG6.5 (2Q), UH6.14 (4A)
/HC2000_7/MV3: UG6.6 (3Q), UH6.10 (3B)
/HC2000_7/MV4: UG6.15 (6Q), UH6.3 (1B)
/HC2000_7/MV5: UG6.12 (5Q), UH6.13 (4B)
/HC2000_7/MV6: UG6.9 (4Q), UH6.5 (2A), UH6.6 (2B)
/HC2000_7/MV7: R72.2, UG6.19 (8Q), UH3.1 (I0)
/HC2000_7/R1: R75.2, UH1.4 (D1), UH6.4 (1Y)
/HC2000_7/VATR0: UF6.19 (8Q), UG6.3 (1D)
/HC2000_7/VATR1: UF6.5 (2Q), UG6.17 (7D)
/HC2000_7/VATR2: UF6.2 (1Q), UG6.4 (2D)
/HC2000_7/VATR3: UF6.16 (7Q), UG6.7 (3D)
/HC2000_7/VATR4: UF6.6 (3Q), UG6.14 (6D)
/HC2000_7/VATR5: UF6.9 (4Q), UG6.13 (5D)
/HC2000_7/VATR6: UF6.12 (5Q), UG6.8 (4D)
/HC2000_7/VATR7: UF6.15 (6Q), UG6.18 (8D)
/HC2000_7/VP0: UD6.2 (1Q), UE6.2 (A)
/HC2000_7/VP1: UD6.6 (3Q), UE6.3 (B)
/HC2000_7/VP2: UD6.15 (6Q), UE6.4 (C)
/HC2000_7/VP3: UD6.5 (2Q), UE6.5 (D)
/HC2000_7/VP4: UD6.9 (4Q), UE6.10 (E)
/HC2000_7/VP5: UD6.12 (5Q), UE6.11 (F)
/HC2000_7/VP6: UD6.16 (7Q), UE6.12 (G)
/HC2000_7/VP7: UD6.19 (8Q), UE6.14 (H)
ATRIB: UF6.11 (CLK); also elsewhere on the board
BLANK: UH1.1 (CLR); also elsewhere on the board
BLUE: R76.1; also elsewhere on the board
BORD: UH6.15 (G); also elsewhere on the board
BRIGHT: UH1.7 (Q2); also elsewhere on the board
DOT: UD6.11 (CLK); also elsewhere on the board
GRN: R74.1; also elsewhere on the board
unnamed: R7.1, R8.2, R9.2, UA7.12 (+IN)
unnamed: C1.1, C3.1, R6.1, UA7.13 (-IN)
unnamed: R6.2, R7.2, UA7.14 (OUT), UH3.2 (I1)
unnamed: UE6.13 (QH), UH4.5 (I1)
unnamed: UH3.3 (O), UH4.4 (I0)
unnamed: UH4.6 (O), UH6.1 (~A/B)
RED: R75.1; also elsewhere on the board
TC1L: UE6.15 (SH/~LD); also elsewhere on the board
VD0: UD6.3 (1D), UF6.18 (8D); also elsewhere on the board
VD1: UD6.7 (3D), UF6.4 (2D); also elsewhere on the board
VD2: UD6.14 (6D), UF6.3 (1D); also elsewhere on the board
VD3: UD6.4 (2D), UF6.17 (7D); also elsewhere on the board
VD4: UD6.8 (4D), UF6.7 (3D); also elsewhere on the board
VD5: UD6.13 (5D), UF6.8 (4D); also elsewhere on the board
VD6: UD6.17 (7D), UF6.13 (5D); also elsewhere on the board
VD7: UD6.18 (8D), UF6.14 (6D); also elsewhere on the board
X1L: UE6.7 (CLK); also elsewhere on the board
X4L: UG6.11 (CLK); also elsewhere on the board

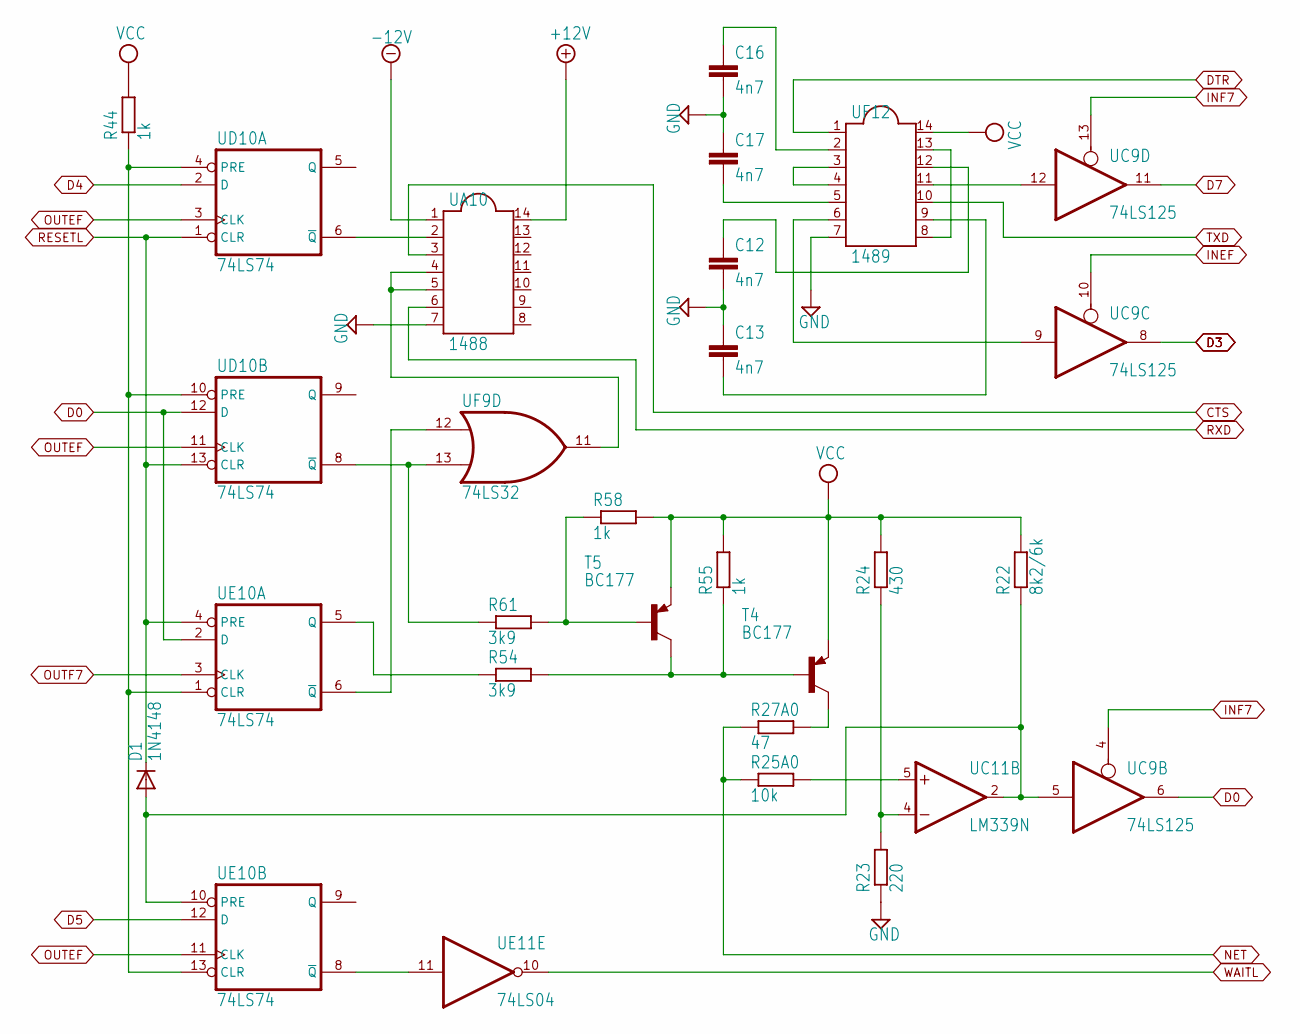
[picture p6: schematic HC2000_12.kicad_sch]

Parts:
C12, C13, C16, C17: 4n7; C025-025X050
D1: 1N4148; DO35-10
R22: 8k2/6k; 0204_7
R23: 220; 0204_7
R24: 430; 0204_7
R25A0: 10k; 0204_7
R27A0: 47; 0204_7
R44, R55, R58: 1k; 0204_7
R54, R61: 3k9; 0204_7
T4, T5: BC177; TO18
UA10: 1488; DIL14
UC9: 74LS125; DIL14
UC11: LM339N; DIL14
UD10: 74LS74; DIL14
UE10: 74LS74; DIL14
UE11: 74LS04; DIL14
UF9: 74LS32; DIL14
UF12: 1489; DIL14

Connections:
+12V: UA10.14; also elsewhere on the board
-12V: UA10.1; also elsewhere on the board
CTS: UA10.3; also elsewhere on the board
D4: UD10.2 (D); also elsewhere on the board
D5: UE10.12 (D); also elsewhere on the board
D7: UC9.11 (O); also elsewhere on the board
DTR: UF12.1; also elsewhere on the board
INEF: UC9.10 (OE); also elsewhere on the board
INF7: UC9.4 (OE), UC9.13 (OE); also elsewhere on the board
NET: R25A0.1, R27A0.1; also elsewhere on the board
unnamed: C12.1, UF12.12
unnamed: C13.2, UF12.9
unnamed: C16.1, UF12.2
unnamed: C17.2, UF12.5
unnamed: R54.2, R55.1, T4.2 (B), T5.3 (C)
unnamed: R27A0.2, T4.3 (C)
unnamed: R58.1, R61.2, T5.2 (B)
unnamed: UC9.9 (I), UF12.6
unnamed: UC9.12 (I), UF12.11
unnamed: R25A0.2, UC11.5 (+IN)
unnamed: R23.2, R24.1, UC11.4 (-IN)
unnamed: D1.A, R22.1, UC9.5 (I), UC11.2 (OUT), UE10.10 (PRE)
unnamed: R44.1, UD10.4 (PRE), UD10.10 (PRE), UE10.1 (CLR), UE10.13 (CLR)
unnamed: UA10.2, UD10.6 (~Q)
unnamed: R61.1, UD10.8 (~Q), UF9.13 (I1)
unnamed: R54.1, UE10.5 (Q)
unnamed: UE10.6 (~Q), UF9.12 (I0)
unnamed: UE10.8 (~Q), UE11.11 (I)
unnamed: UA10.4, UA10.5, UF9.11 (O)
unnamed: UF12.3, UF12.4
unnamed: UF12.8, UF12.13
OUTEF: UD10.3 (CLK), UD10.11 (CLK), UE10.11 (CLK); also elsewhere on the board
OUTF7: UE10.3 (CLK); also elsewhere on the board
RESETL: D1.C, UD10.1 (CLR), UD10.13 (CLR), UE10.4 (PRE); also elsewhere on the board
RXD: UA10.6; also elsewhere on the board
TXD: UF12.10; also elsewhere on the board
WAITL: UE11.10 (O); also elsewhere on the board

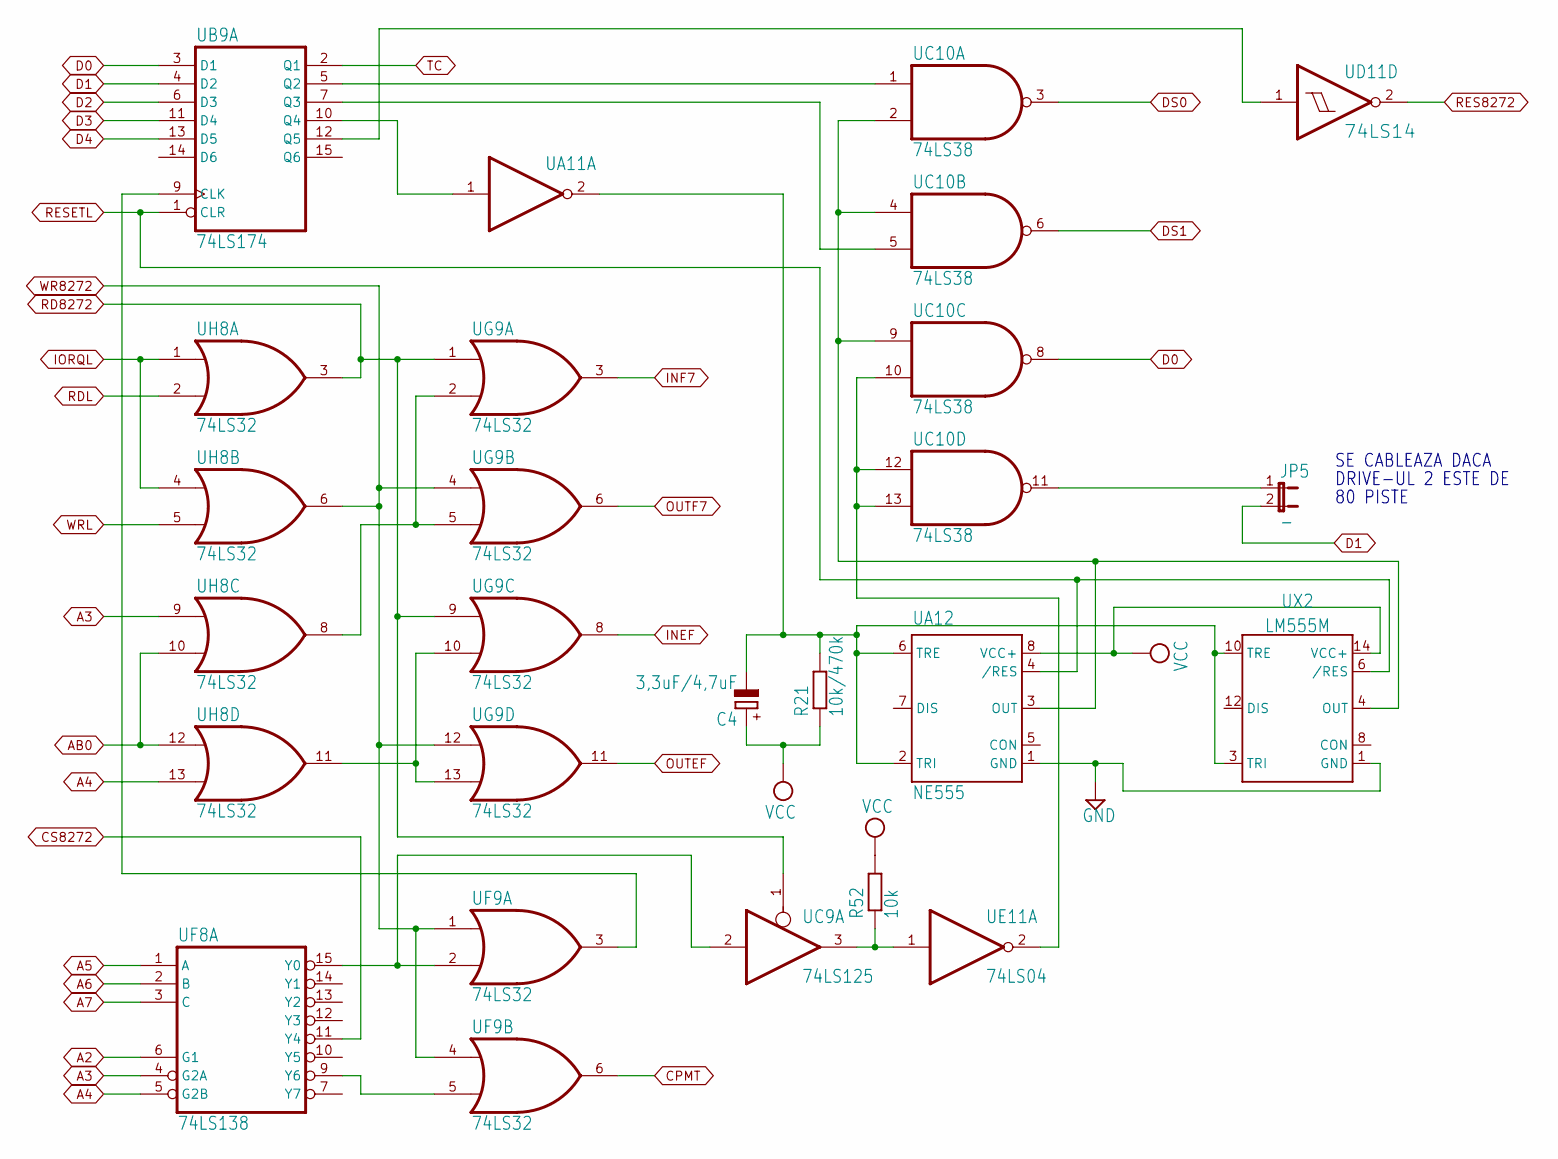
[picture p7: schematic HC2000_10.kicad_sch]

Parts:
C4: 3,3uF/4,7uF; C025-024X044
JP5: -; JP1
R21: 10k/470k; 0204_7
R52: 10k; 0204_7
UA11: 74LS06; DIL14
UA12: NE555; DIL-08
UB9: 74LS174; DIL16
UC9: 74LS125; DIL14
UC10: 74LS38; DIL14
UD11: 74LS14; DIL14
UE11: 74LS04; DIL14
UF8: 74LS138; DIL16
UF9: 74LS32; DIL14
UG9: 74LS32; DIL14
UH8: 74LS32; DIL14
UX2: LM555M; DIL14

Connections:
AB0: UH8.10 (I1), UH8.12 (I0); also elsewhere on the board
CPMT: UF9.6 (O); also elsewhere on the board
CS8272: UF8.11 (Y4); also elsewhere on the board
D4: UB9.13 (D5); also elsewhere on the board
DS0: UC10.3 (O); also elsewhere on the board
DS1: UC10.6 (O); also elsewhere on the board
INEF: UG9.8 (O); also elsewhere on the board
INF7: UG9.3 (O); also elsewhere on the board
IORQL: UH8.1 (I0), UH8.4 (I0); also elsewhere on the board
unnamed: UA11.1 (I), UB9.10 (Q4)
unnamed: C4.-, R21.2, UA11.2 (O), UA12.2 (TRI), UA12.6 (TRE), UX2.3 (TRI), UX2.10 (TRE)
unnamed: UA12.3 (OUT), UC10.2 (I1), UC10.4 (I0), UC10.9 (I0), UX2.4 (OUT)
unnamed: UB9.9 (CLK), UF9.3 (O)
unnamed: UB9.5 (Q2), UC10.1 (I0)
unnamed: UB9.7 (Q3), UC10.5 (I1)
unnamed: UB9.12 (Q5), UD11.1 (I)
unnamed: UC9.2 (I), UF8.15 (Y0), UF9.2 (I1)
unnamed: R52.1, UC9.3 (O), UE11.1 (I)
unnamed: UC10.10 (I1), UC10.12 (I0), UC10.13 (I1), UE11.2 (O)
unnamed: JP5.1, UC10.11 (O)
unnamed: UF8.9 (Y6), UF9.5 (I1)
unnamed: UG9.2 (I1), UG9.5 (I1), UH8.8 (O)
unnamed: UG9.10 (I1), UG9.13 (I1), UH8.11 (O)
OUTEF: UG9.11 (O); also elsewhere on the board
OUTF7: UG9.6 (O); also elsewhere on the board
RD8272: UC9.1 (OE), UG9.1 (I0), UG9.9 (I0), UH8.3 (O); also elsewhere on the board
RDL: UH8.2 (I1); also elsewhere on the board
RES8272: UD11.2 (O); also elsewhere on the board
RESETL: UA12.4 (/RES), UB9.1 (CLR), UX2.6 (/RES); also elsewhere on the board
TC: UB9.2 (Q1); also elsewhere on the board
WR8272: UF9.1 (I0), UF9.4 (I0), UG9.4 (I0), UG9.12 (I0), UH8.6 (O); also elsewhere on the board
WRL: UH8.5 (I1); also elsewhere on the board

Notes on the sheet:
80 PISTE
SE CABLEAZA DACA
DRIVE-UL 2 ESTE DE

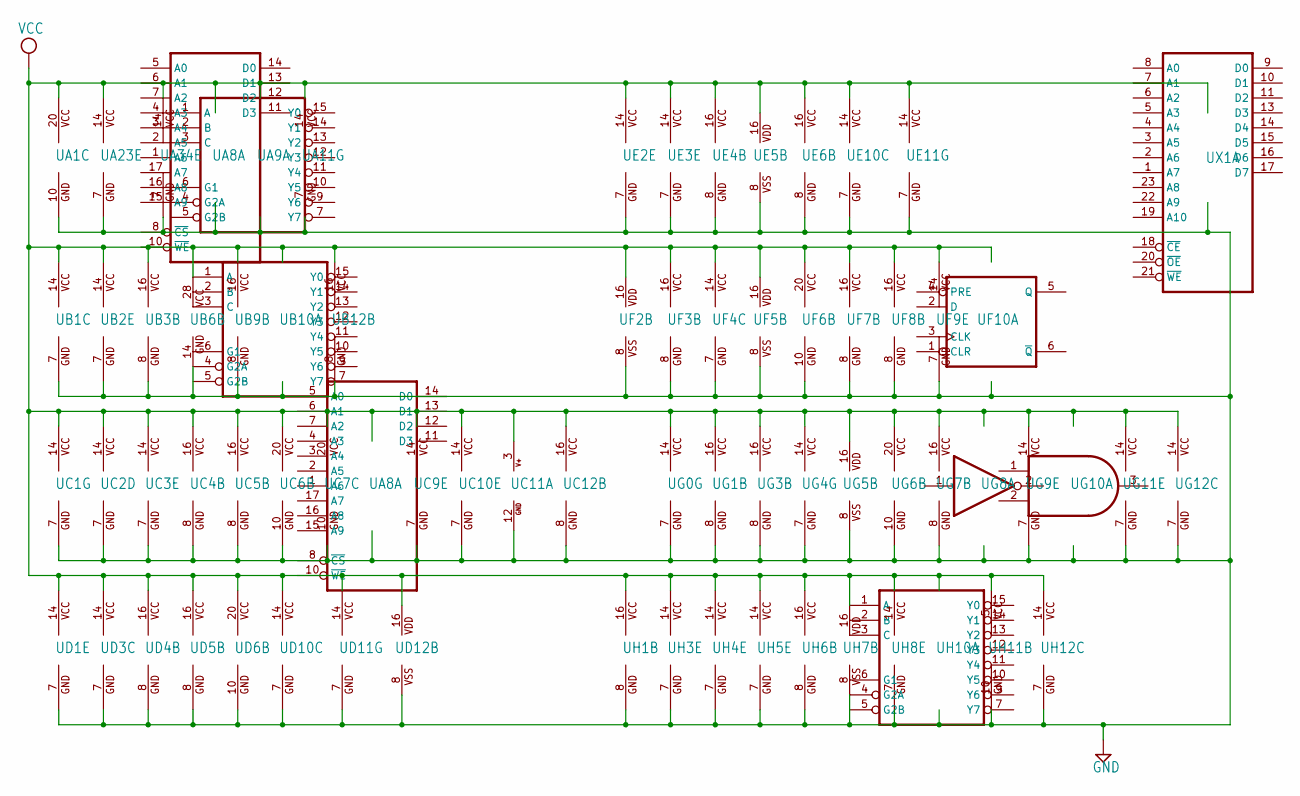
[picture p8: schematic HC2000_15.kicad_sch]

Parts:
UA1: 74LS244; DIL20
UA8: 2k x 4bit CMOS RAM/-; DIL18
UA9: 74LS138; DIL16
UA11: 74LS06; DIL14
UA23, UA34: 74LS09; DIL14
UB1: 74LS74; DIL14
UB2: 74LS00; DIL14
UB3: 74LS367; DIL16
UB6: 27C256/27C512; DIL28
UB9: 74LS174; DIL16
UB10: 74LS138; DIL16
UB12: 74LS153; DIL16
UC1: 74LS04; DIL14
UC2: 74LS27; DIL14
UC3: 74LS32; DIL14
UC4, UC5: 74LS257; DIL16
UC6: 74LS373; DIL20
UC7: 74LS244; DIL20
UC9: 74LS125; DIL14
UC10: 74LS38; DIL14
UC11: LM339N; DIL14
UC12: 74LS175; DIL16
UD1: 74LS08; DIL14
UD3, UD10: 74LS74; DIL14
UD4: 74LS157; DIL16
UD5: 74LS257; DIL16
UD6: 74LS374; DIL20
UD11: 74LS14; DIL14
UD12: 74LS161; DIL16
UE2: 74LS08; DIL14
UE3: 74LS32; DIL14
UE4: 74LS138; DIL16
UE5: 74LS161; DIL16
UE6: 74LS166; DIL16
UE10: 74LS74; DIL14
UE11: 74LS04; DIL14
UF2, UF5: 74LS161; DIL16
UF3: 74LS175; DIL16
UF4, UF10: 74LS74; DIL14
UF6: 74LS374; DIL20
UF7: 74LS174; DIL16
UF8: 74LS138; DIL16
UF9: 74LS32; DIL14
UG0, UG4: 74LS04; DIL14
UG1: 74LS42; DIL16
UG3: 74LS175; DIL16
UG5: 74LS161; DIL16
UG6: 74LS374; DIL20
UG7: 74LS257; DIL16
UG8: 74LS05; DIL14
UG9: 74LS32; DIL14
UG10, UG11: 74LS08; DIL14
UG12: 74LS74; DIL14
UH1: 74LS175; DIL16
UH3: 74LS00; DIL14
UH4: 74LS86; DIL14
UH5: 74LS08; DIL14
UH6: 74LS257; DIL16
UH7: 74LS161; DIL16
UH8: 74LS32; DIL14
UH10: 74LS138; DIL16
UH11: 74LS93; DIL14
UH12: 74LS74; DIL14
UX1: UM6116-3; DIL24

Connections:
/HC2000_11/PHANTOM: UB10.6 (G1), UF10.5 (Q); also elsewhere on the board
A15: UB10.5 (G2B); also elsewhere on the board
D4: UA8.14 (D0), UX1.14 (D4); also elsewhere on the board
D5: UA8.13 (D1), UX1.15 (D5); also elsewhere on the board
D6: UA8.12 (D2), UX1.16 (D6); also elsewhere on the board
D7: UA8.11 (D3), UX1.17 (D7); also elsewhere on the board
M1L: UA9.4 (G2A); also elsewhere on the board
unnamed 133: UA8.8 (~CS), UB10.14 (Y1), UX1.18 (~CE); also elsewhere on the board
unnamed 134: UF10.6 (~Q); also elsewhere on the board
unnamed 157: UA9.6 (G1), UG8.2 (O); also elsewhere on the board
unnamed 158: UA9.5 (G2B); also elsewhere on the board
unnamed 159: UA9.15 (Y0), UH10.2 (B); also elsewhere on the board
unnamed 160: UA9.7 (Y7); also elsewhere on the board
unnamed 181: UB10.15 (Y0); also elsewhere on the board
unnamed: UF10.3 (CLK), UH10.13 (Y2)
unnamed 245: UF10.4 (PRE); also elsewhere on the board
unnamed 261: UH10.6 (G1); also elsewhere on the board
unnamed 262: UH10.14 (Y1); also elsewhere on the board
unnamed 263: UH10.7 (Y7); also elsewhere on the board
RESETL: UF10.1 (CLR); also elsewhere on the board
WRL: UA8.10 (~WE), UX1.21 (~WE); also elsewhere on the board

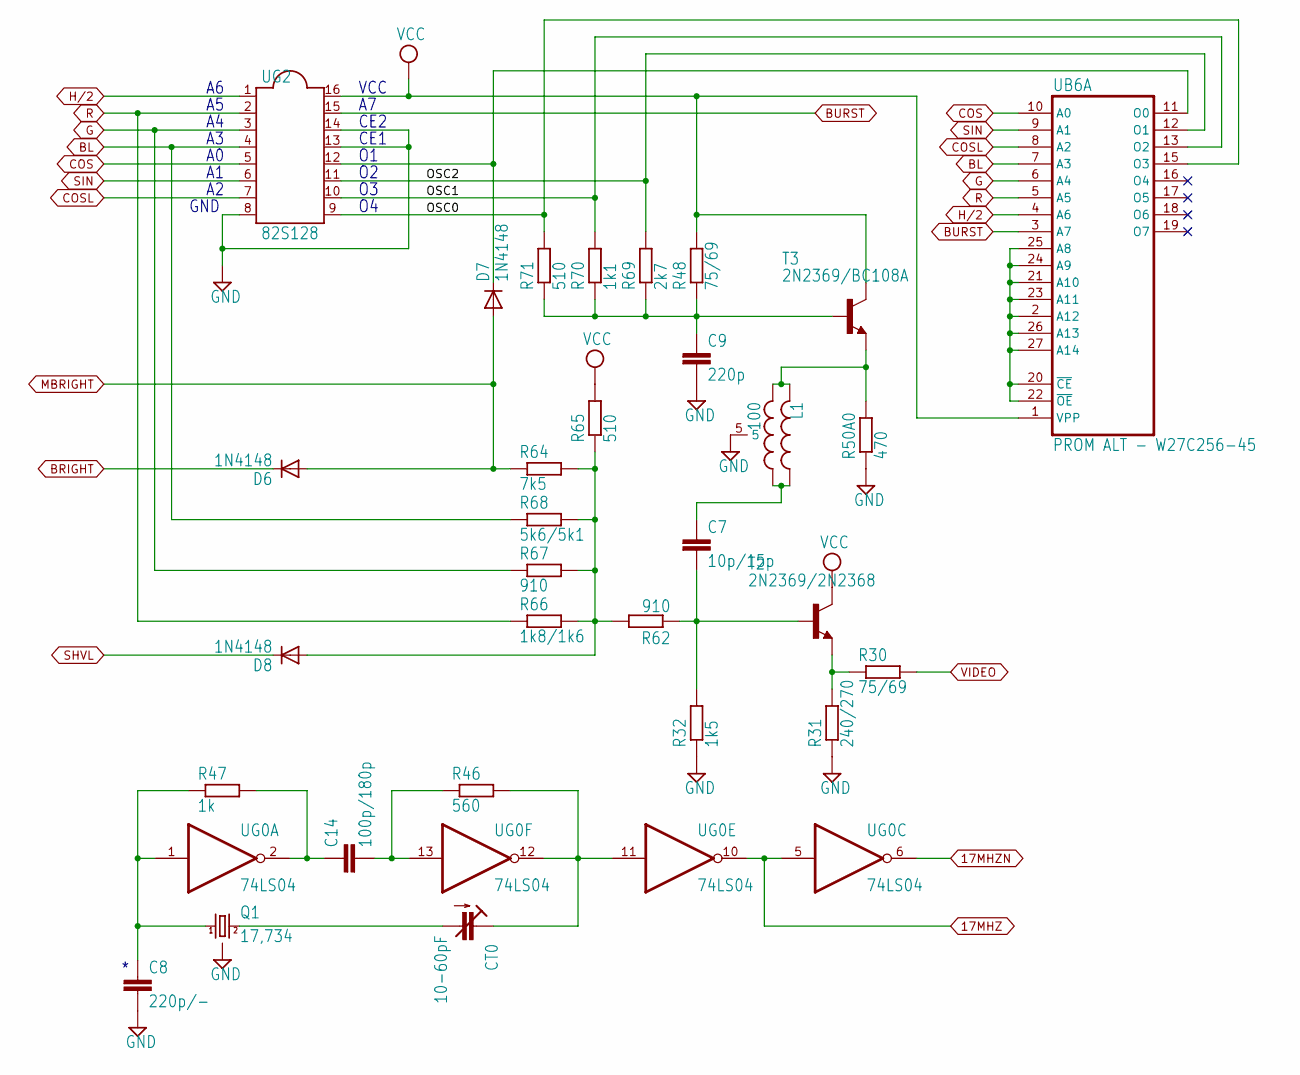
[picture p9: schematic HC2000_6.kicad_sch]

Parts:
C7: 10p/15p; C025-030X050
C8: 220p/-; C025-030X050
C9: 220p; C025-030X050
C14: 100p/180p; C025-030X050
CT0: 10-60pF; CTRIM808-BC
D6, D7, D8: 1N4148; DO35-10
L1: 100; PIS2816
Q1: 17,734; HC18U-H
R30, R48: 75/69; 0204_7
R31: 240/270; 0204_7
R32: 1k5; 0204_7
R46: 560; 0204_7
R47: 1k; 0204_7
R50A0: 470; 0204_7
R62, R67: 910; 0204_7
R64: 7k5; 0204_7
R65, R71: 510; 0204_7
R66: 1k8/1k6; 0204_7
R68: 5k6/5k1; 0204_7
R69: 2k7; 0204_7
R70: 1k1; 0204_7
T2: 2N2369/2N2368; TO18
T3: 2N2369/BC108A; TO18
UB6: PROM ALT - W27C256-45; DIL28
UG0: 74LS04; DIL14
UG2: 82S128; DIL16

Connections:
17MHZ: UG0.5 (I), UG0.10 (O); also elsewhere on the board
17MHZN: UG0.6 (O); also elsewhere on the board
BRIGHT: D6.C; also elsewhere on the board
D4: UB6.16 (O4); also elsewhere on the board
D5: UB6.17 (O5); also elsewhere on the board
D6: UB6.18 (O6); also elsewhere on the board
D7: UB6.19 (O7); also elsewhere on the board
MBRIGHT: D6.A, D7.A, R64.1; also elsewhere on the board
unnamed: C7.1, L1.1, L1.4
unnamed: CT0.2 (A), Q1.2
unnamed: D8.A, R62.2, R64.2, R65.1, R66.2, R67.2, R68.2
unnamed: C7.2, R32.2, R62.1, T2.2 (B)
unnamed: R30.1, R31.2, T2.1 (E)
unnamed: C9.1, R48.1, R69.1, R70.1, R71.1, T3.2 (B)
unnamed: L1.2, L1.3, R50A0.2, T3.1 (E)
unnamed: C8.1, Q1.1, R47.1, UG0.1 (I)
unnamed: C14.1, R47.2, UG0.2 (O)
unnamed: CT0.1 (E), CT0.3 (E), R46.2, UG0.11 (I), UG0.12 (O)
unnamed: C14.2, R46.1, UG0.13 (I)
SHVL: D8.C; also elsewhere on the board
VIDEO: R30.2; also elsewhere on the board

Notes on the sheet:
VCC
CE2
GND
CE1

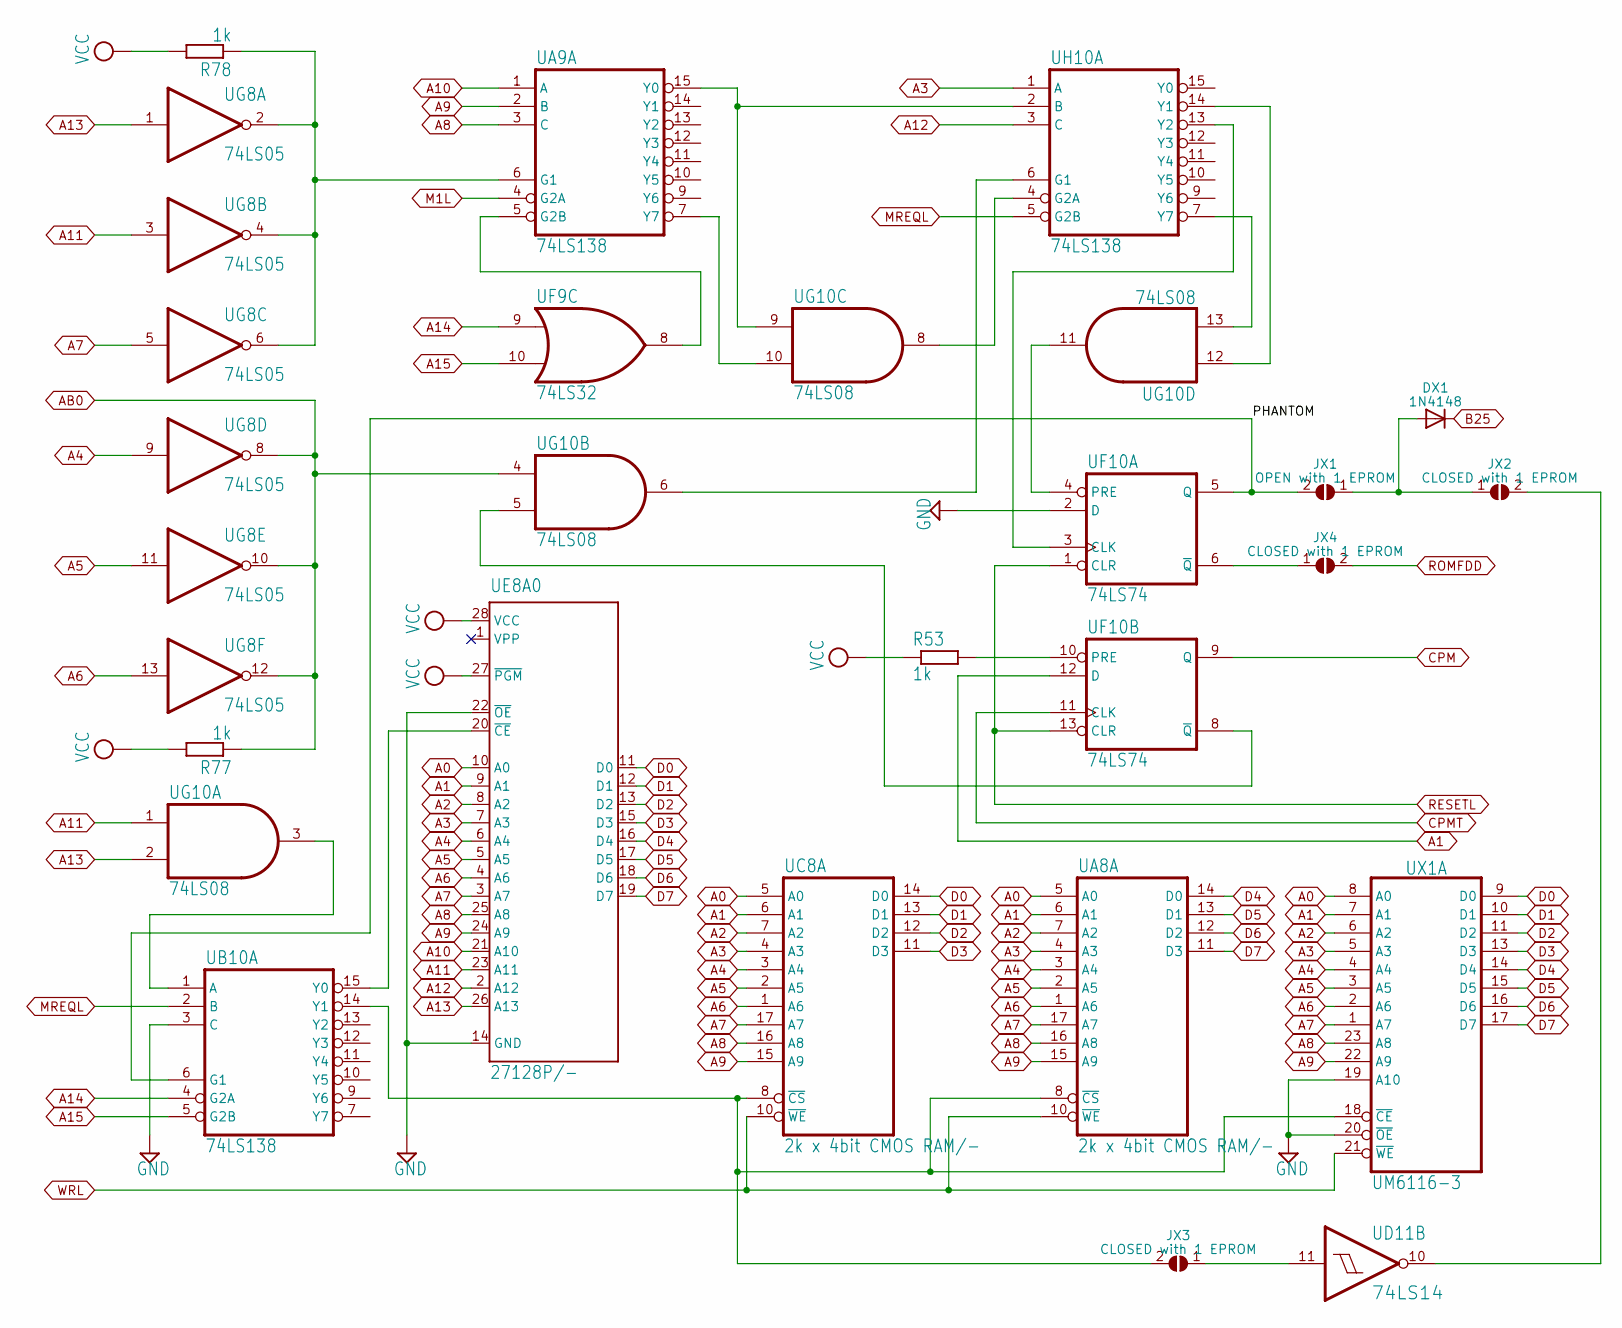
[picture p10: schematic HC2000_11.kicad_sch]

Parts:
DX1: 1N4148; DO35-7
JX1: OPEN with 1 EPROM; SolderJumper-2_P1.3mm_Open_Pad1.0x1.5mm
JX2, JX3, JX4: CLOSED with 1 EPROM; SolderJumper-2_P1.3mm_Open_Pad1.0x1.5mm
R53, R77, R78: 1k; 0204_7
UA8: 2k x 4bit CMOS RAM/-; DIL18
UA9: 74LS138; DIL16
UB10: 74LS138; DIL16
UC8: 2k x 4bit CMOS RAM/-; DIL18
UD11: 74LS14; DIL14
UE8A0: 27128P/-; DIL28-6
UF9: 74LS32; DIL14
UF10: 74LS74; DIL14
UG8: 74LS05; DIL14
UG10: 74LS08; DIL14
UH10: 74LS138; DIL16
UX1: UM6116-3; DIL24

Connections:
/HC2000_11/PHANTOM: JX1.2 (B), UB10.6 (G1), UF10.5 (Q)
A15: UB10.5 (G2B), UF9.10 (I1); also elsewhere on the board
AB0: R77.1, UG8.8 (O), UG8.10 (O), UG8.12 (O), UG10.4 (I0); also elsewhere on the board
B25: DX1.C; also elsewhere on the board
CPM: UF10.9 (Q); also elsewhere on the board
CPMT: UF10.11 (CLK); also elsewhere on the board
D4: UA8.14 (D0), UE8A0.16 (D4), UX1.14 (D4); also elsewhere on the board
D5: UA8.13 (D1), UE8A0.17 (D5), UX1.15 (D5); also elsewhere on the board
D6: UA8.12 (D2), UE8A0.18 (D6), UX1.16 (D6); also elsewhere on the board
D7: UA8.11 (D3), UE8A0.19 (D7), UX1.17 (D7); also elsewhere on the board
M1L: UA9.4 (G2A); also elsewhere on the board
unnamed: DX1.A, JX1.1 (A), JX2.1 (A)
unnamed: JX3.2 (B), UA8.8 (~CS), UB10.14 (Y1), UC8.8 (~CS), UX1.18 (~CE)
unnamed: JX4.1 (A), UF10.6 (~Q)
unnamed: R78.1, UA9.6 (G1), UG8.2 (O), UG8.4 (O), UG8.6 (O)
unnamed: UA9.5 (G2B), UF9.8 (O)
unnamed: UA9.15 (Y0), UG10.9 (I0), UH10.2 (B)
unnamed: UA9.7 (Y7), UG10.10 (I1)
unnamed: UB10.15 (Y0), UE8A0.20 (~CE)
unnamed: UF10.3 (CLK), UH10.13 (Y2)
unnamed: UF10.4 (PRE), UG10.11 (O)
unnamed: R53.2, UF10.10 (PRE)
unnamed: UF10.8 (~Q), UG10.5 (I1)
unnamed: UG10.6 (O), UH10.6 (G1)
unnamed: UG10.12 (I0), UH10.14 (Y1)
unnamed: UG10.13 (I1), UH10.7 (Y7)
RESETL: UF10.1 (CLR), UF10.13 (CLR); also elsewhere on the board
WRL: UA8.10 (~WE), UC8.10 (~WE), UX1.21 (~WE); also elsewhere on the board

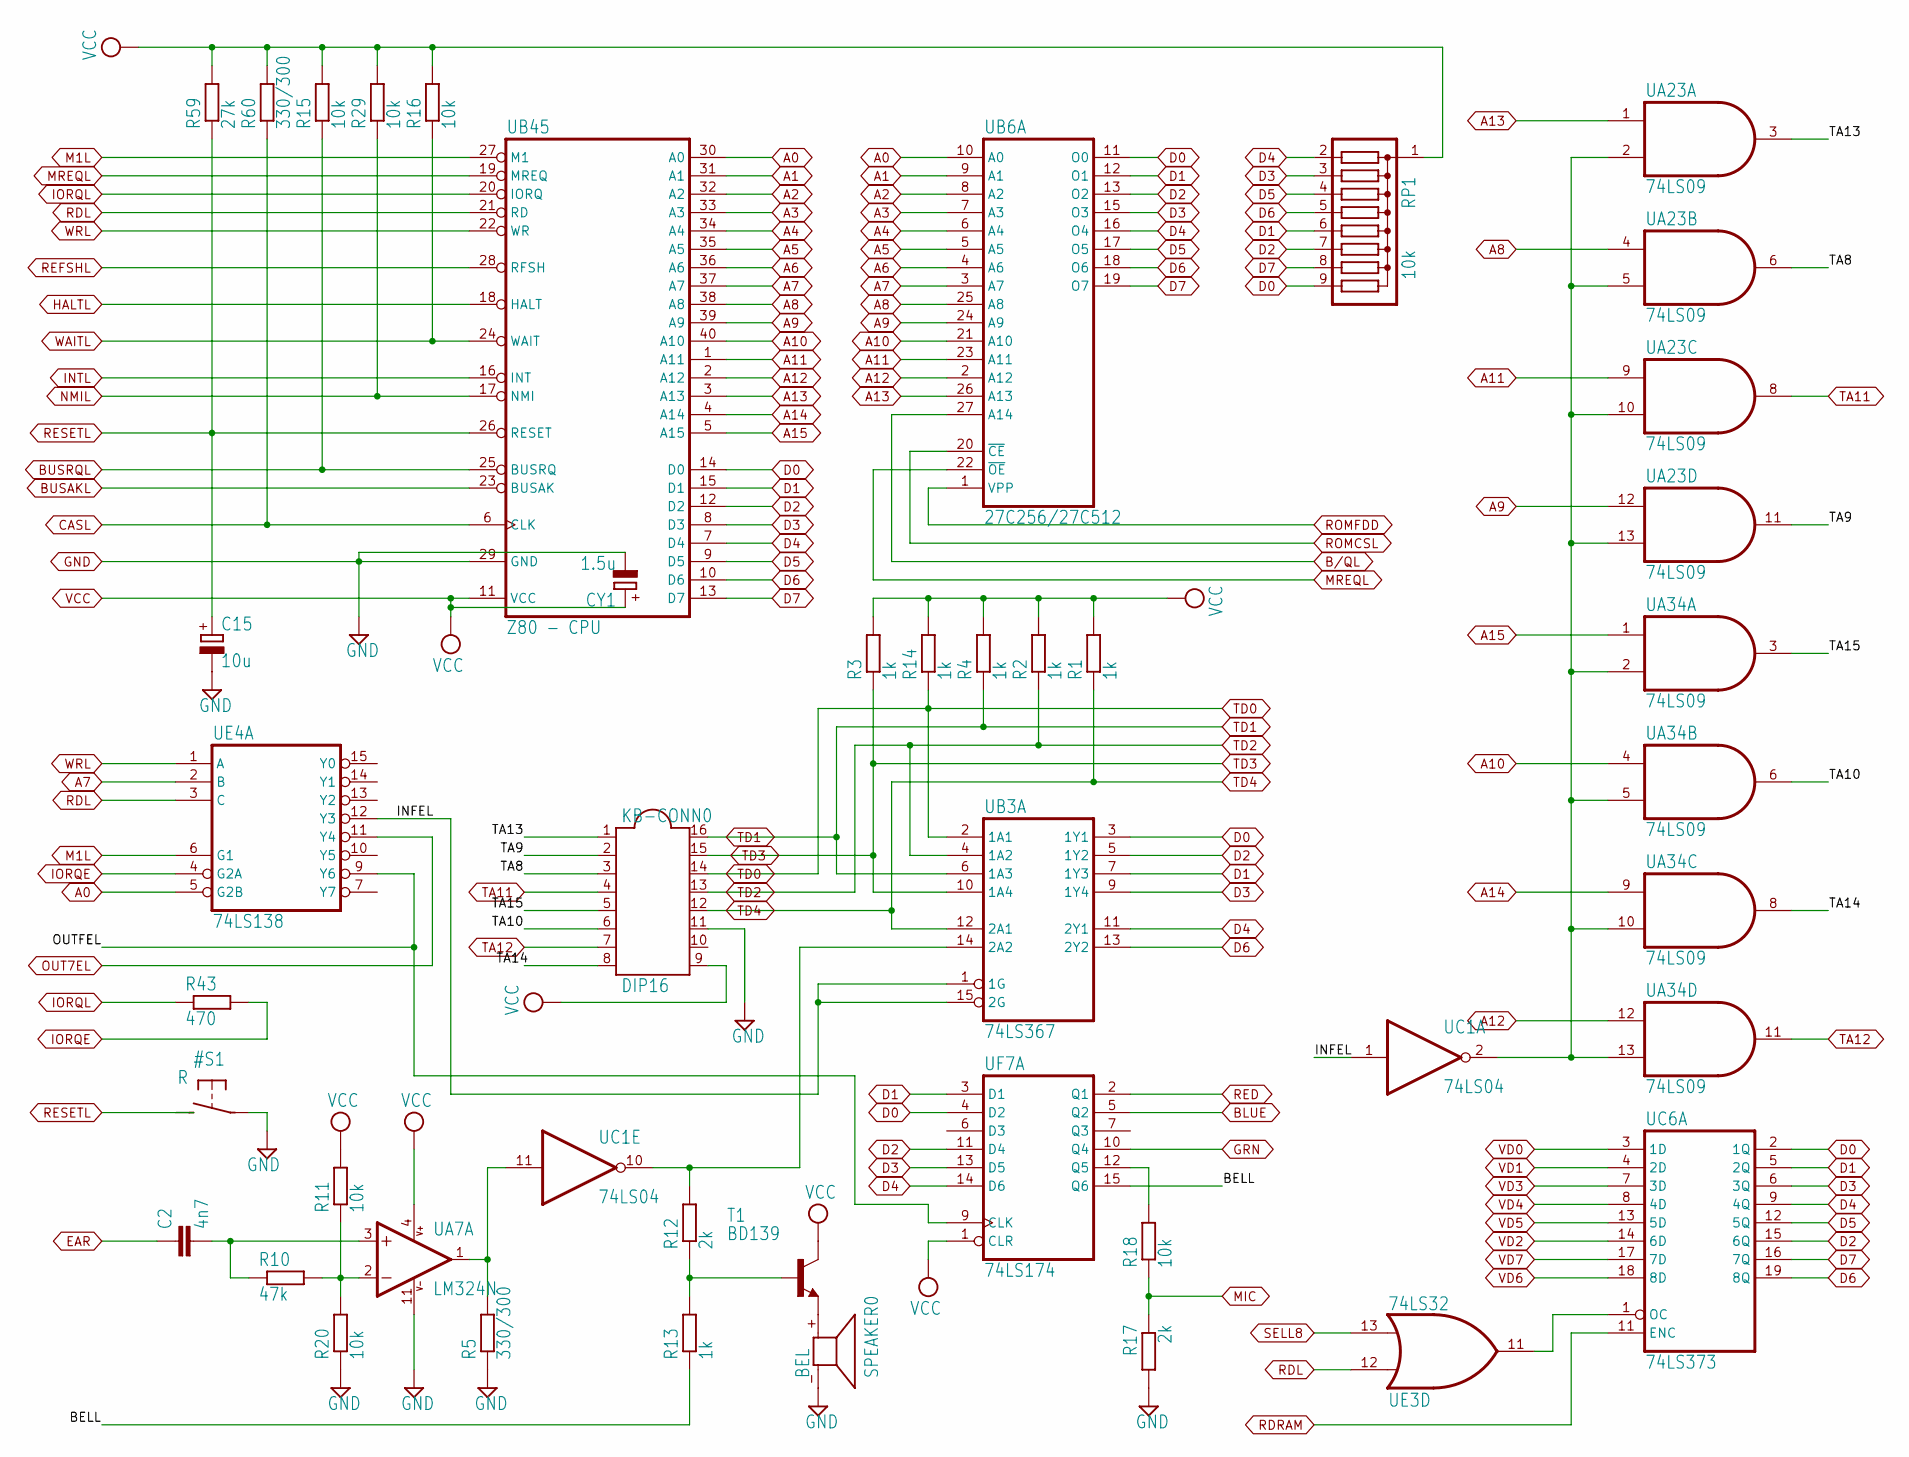
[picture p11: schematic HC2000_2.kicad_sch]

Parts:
C2: 4n7; C025-030X050
C15: 10u; C025-024X024
CY1: 1.5u
KB-CONN0: DIP16; DIL16
R1, R2, R3, R4, R13, R14: 1k; 0204_7
R5, R60: 330/300; 0204_7
R10: 47k; 0204_7
R11, R15, R16, R18, R20, R29: 10k; 0204_7
R12, R17: 2k; 0204_7
R43: 470; 0204_7
R59: 27k; 0204_7
RP1: 10k; SIL9
SPEAKER0: BEL; AL11P
T1: BD139; TO-126-3_Vertical
UA7: LM324N; DIL14
UA23, UA34: 74LS09; DIL14
UB3: 74LS367; DIL16
UB6: 27C256/27C512; DIL28
UB45: Z80 - CPU; DIL40
UC1: 74LS04; DIL14
UC6: 74LS373; DIL20
UE3: 74LS32; DIL14
UE4: 74LS138; DIL16
UF7: 74LS174; DIL16

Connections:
/HC2000_2/BELL: R13.1, UF7.15 (Q6)
/HC2000_2/INFEL: UB3.1 (1G), UB3.15 (2G), UC1.1 (I), UE4.12 (Y3)
/HC2000_2/OUTFEL: UE4.9 (Y6), UF7.9 (CLK)
/HC2000_2/TA8: KB-CONN0.3, UA23.6 (O)
/HC2000_2/TA9: KB-CONN0.2, UA23.11 (O)
/HC2000_2/TA10: KB-CONN0.6, UA34.6 (O)
/HC2000_2/TA13: KB-CONN0.1, UA23.3 (O)
/HC2000_2/TA14: KB-CONN0.8, UA34.8 (O)
/HC2000_2/TA15: KB-CONN0.5, UA34.3 (O)
A15: UA34.1 (I0), UB45.5 (A15); also elsewhere on the board
BLUE: UF7.5 (Q2); also elsewhere on the board
BUSAKL: UB45.23 (BUSAK); also elsewhere on the board
BUSRQL: R15.1, UB45.25 (BUSRQ); also elsewhere on the board
CASL: R60.1, UB45.6 (CLK); also elsewhere on the board
D4: RP1.2, UB3.11 (2Y1), UB6.16 (O4), UB45.7 (D4), UC6.9 (4Q), UF7.14 (D6); also elsewhere on the board
D5: RP1.4, UB6.17 (O5), UB45.9 (D5), UC6.12 (5Q); also elsewhere on the board
D6: RP1.5, UB3.13 (2Y2), UB6.18 (O6), UB45.10 (D6), UC6.19 (8Q); also elsewhere on the board
D7: RP1.8, UB6.19 (O7), UB45.13 (D7), UC6.16 (7Q); also elsewhere on the board
EAR: C2.1; also elsewhere on the board
GRN: UF7.10 (Q4); also elsewhere on the board
HALTL: UB45.18 (HALT); also elsewhere on the board
INTL: UB45.16 (INT); also elsewhere on the board
IORQE: R43.2, UE4.4 (G2A); also elsewhere on the board
IORQL: R43.1, UB45.20 (IORQ); also elsewhere on the board
M1L: UB45.27 (M1), UE4.6 (G1); also elsewhere on the board
MIC: R17.1, R18.1; also elsewhere on the board
NMIL: R29.1, UB45.17 (NMI); also elsewhere on the board
unnamed: SPEAKER0.+ (2), T1.1 (E)
unnamed: R12.1, R13.2, T1.3 (B)
unnamed: C2.2, R10.1, UA7.3 (+IN)
unnamed: R10.2, R11.1, R20.2, UA7.2 (-IN)
unnamed: R5.2, UA7.1 (OUT), UC1.11 (I)
unnamed: UA23.2 (I1), UA23.5 (I1), UA23.10 (I1), UA23.13 (I1), UA34.2 (I1), UA34.5 (I1), UA34.10 (I1), UA34.13 (I1), UC1.2 (O)
unnamed: R12.2, UB3.14 (2A2), UC1.10 (O)
unnamed: UC6.1 (OC), UE3.11 (O)
unnamed: R18.2, UF7.12 (Q5)
OUT7EL: UE4.11 (Y4); also elsewhere on the board
RDL: UB45.21 (RD), UE3.12 (I0), UE4.3 (C); also elsewhere on the board
RDRAM: UC6.11 (ENC); also elsewhere on the board
RED: UF7.2 (Q1); also elsewhere on the board
REFSHL: UB45.28 (RFSH); also elsewhere on the board
RESETL: C15.+, R59.1, UB45.26 (RESET); also elsewhere on the board
SELL8: UE3.13 (I1); also elsewhere on the board
TA11: KB-CONN0.4, UA23.8 (O); also elsewhere on the board
TA12: KB-CONN0.7, UA34.11 (O); also elsewhere on the board
TD0: KB-CONN0.14, R14.1, UB3.2 (1A1); also elsewhere on the board
TD1: KB-CONN0.16, R4.1, UB3.6 (1A3); also elsewhere on the board
TD2: KB-CONN0.13, R2.1, UB3.4 (1A2); also elsewhere on the board
TD3: KB-CONN0.15, R3.1, UB3.10 (1A4); also elsewhere on the board
TD4: KB-CONN0.12, R1.1, UB3.12 (2A1); also elsewhere on the board
VD0: UC6.3 (1D); also elsewhere on the board
VD1: UC6.4 (2D); also elsewhere on the board
VD2: UC6.14 (6D); also elsewhere on the board
VD3: UC6.7 (3D); also elsewhere on the board
VD4: UC6.8 (4D); also elsewhere on the board
VD5: UC6.13 (5D); also elsewhere on the board
VD6: UC6.18 (8D); also elsewhere on the board
VD7: UC6.17 (7D); also elsewhere on the board
WAITL: R16.1, UB45.24 (WAIT); also elsewhere on the board
WRL: UB45.22 (WR), UE4.1 (A); also elsewhere on the board

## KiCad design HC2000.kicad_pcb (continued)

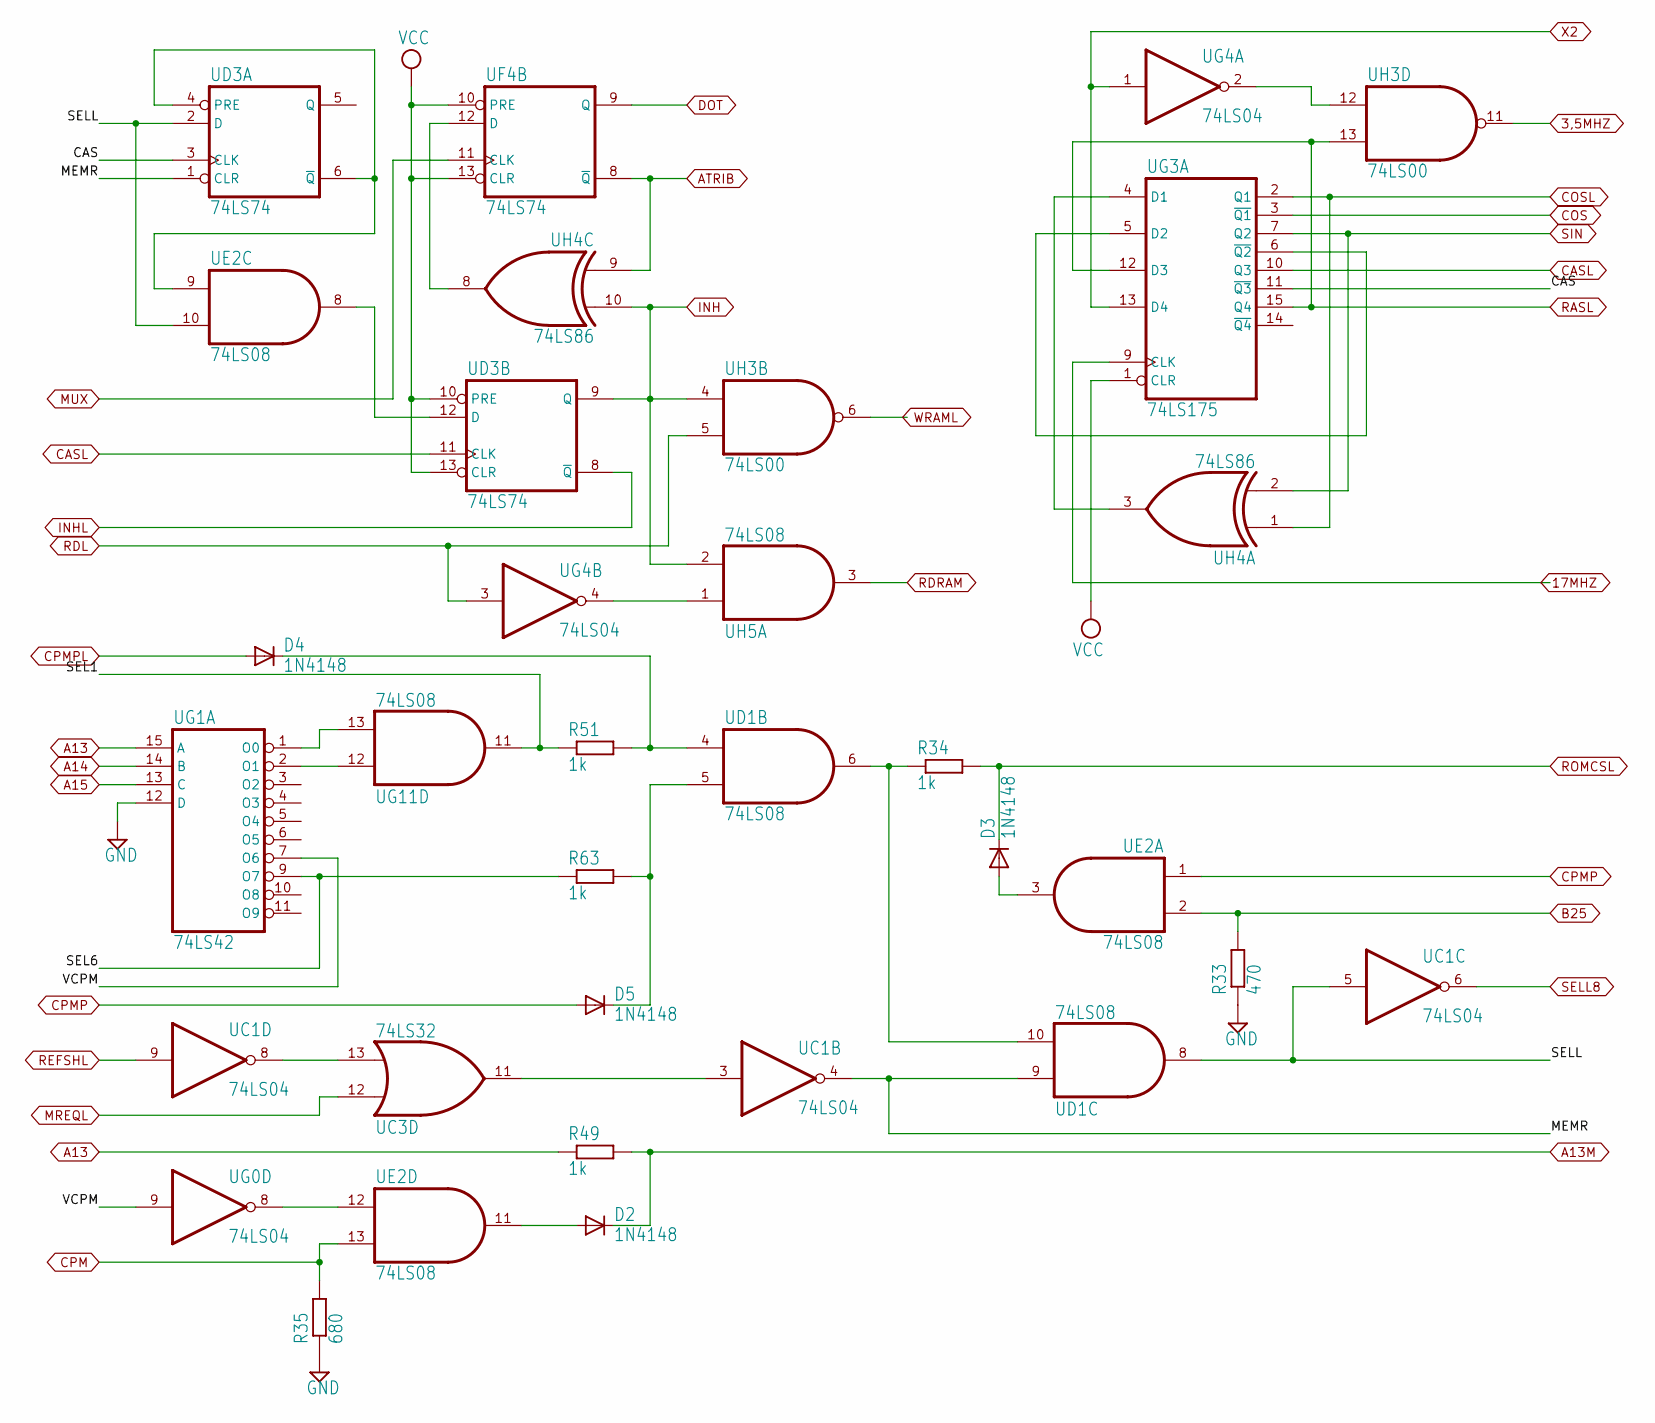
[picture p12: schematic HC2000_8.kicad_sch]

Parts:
D2, D3, D4, D5: 1N4148; DO35-10
R33: 470; 0204_7
R34, R49, R51, R63: 1k; 0204_7
R35: 680; 0204_7
UC1: 74LS04; DIL14
UC3: 74LS32; DIL14
UD1: 74LS08; DIL14
UD3: 74LS74; DIL14
UE2: 74LS08; DIL14
UF4: 74LS74; DIL14
UG0, UG4: 74LS04; DIL14
UG1: 74LS42; DIL16
UG3: 74LS175; DIL16
UG11: 74LS08; DIL14
UH3: 74LS00; DIL14
UH4: 74LS86; DIL14
UH5: 74LS08; DIL14

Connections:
3,5MHZ: UH3.11 (O); also elsewhere on the board
17MHZ: UG3.9 (CLK); also elsewhere on the board
/HC2000_8/CAS: UD3.3 (CLK), UG3.11 (~Q3)
/HC2000_8/MEMR: UC1.4 (O), UD1.9 (I0), UD3.1 (CLR)
/HC2000_8/SEL1: R51.1, UG11.11 (O)
/HC2000_8/SEL6: R63.1, UG1.9 (O7)
/HC2000_8/SELL: UC1.5 (I), UD1.8 (O), UD3.2 (D), UE2.10 (I1)
/HC2000_8/VCPM: UG0.9 (I), UG1.7 (O6)
A13M: D2.C, R49.2; also elsewhere on the board
A15: UG1.13 (C); also elsewhere on the board
ATRIB: UF4.8 (~Q), UH4.9 (I0); also elsewhere on the board
B25: R33.2, UE2.2 (I1); also elsewhere on the board
CASL: UD3.11 (CLK), UG3.10 (Q3); also elsewhere on the board
CPM: R35.2, UE2.13 (I1); also elsewhere on the board
CPMP: D5.A, UE2.1 (I0); also elsewhere on the board
CPMPL: D4.A; also elsewhere on the board
DOT: UF4.9 (Q); also elsewhere on the board
INH: UD3.9 (Q), UH3.4 (I0), UH4.10 (I1), UH5.2 (I1); also elsewhere on the board
INHL: UD3.8 (~Q); also elsewhere on the board
MUX: UF4.11 (CLK); also elsewhere on the board
unnamed: UC1.3 (I), UC3.11 (O)
unnamed: UC1.8 (O), UC3.13 (I1)
unnamed: D4.C, R51.2, UD1.4 (I0)
unnamed: D5.C, R63.2, UD1.5 (I1)
unnamed: R34.1, UD1.6 (O), UD1.10 (I1)
unnamed: UD3.4 (PRE), UD3.6 (~Q), UE2.9 (I0)
unnamed: UD3.12 (D), UE2.8 (O)
unnamed: D3.A, UE2.3 (O)
unnamed: UE2.12 (I0), UG0.8 (O)
unnamed: D2.A, UE2.11 (O)
unnamed: UF4.12 (D), UH4.8 (O)
unnamed: UG3.4 (D1), UH4.3 (O)
unnamed: UG3.5 (D2), UG3.6 (~Q2)
unnamed: UG4.2 (O), UH3.12 (I0)
unnamed: UG4.4 (O), UH5.1 (I0)
unnamed: UG1.2 (O1), UG11.12 (I0)
unnamed: UG1.1 (O0), UG11.13 (I1)
RASL: UG3.12 (D3), UG3.15 (Q4), UH3.13 (I1); also elsewhere on the board
RDL: UG4.3 (I), UH3.5 (I1); also elsewhere on the board
RDRAM: UH5.3 (O); also elsewhere on the board
REFSHL: UC1.9 (I); also elsewhere on the board
SELL8: UC1.6 (O); also elsewhere on the board
WRAML: UH3.6 (O); also elsewhere on the board
X2: UG3.13 (D4), UG4.1 (I); also elsewhere on the board

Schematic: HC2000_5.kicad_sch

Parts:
C6: 150p; C025-030X050
R36: 100; 0204_7
UC4, UC5: 74LS257; DIL16
UC7: 74LS244; DIL20
UD5: 74LS257; DIL16
UD7: TMM41464AP-12; DIL18
UE2: 74LS08; DIL14
UE3: 74LS32; DIL14
UE7: TMM41464AP-12; DIL18
UF3: 74LS175; DIL16
UG7: 74LS257; DIL16

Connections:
/HC2000_5/CVS: UD5.14 (4A), UF3.7 (Q2)
/HC2000_5/VMA0: UC5.4 (1Y), UD7.14 (A0), UE7.14 (A0), UG7.9 (3Y)
/HC2000_5/VMA1: UC5.9 (3Y), UD7.13 (A1), UE7.13 (A1), UG7.4 (1Y)
/HC2000_5/VMA2: UC5.12 (4Y), UD7.12 (A2), UE7.12 (A2), UG7.7 (2Y)
/HC2000_5/VMA3: UC5.7 (2Y), UD7.11 (A3), UE7.11 (A3), UG7.12 (4Y)
/HC2000_5/VMA4: UC4.9 (3Y), UD5.9 (3Y), UD7.8 (A4), UE7.8 (A4)
/HC2000_5/VMA5: UC4.7 (2Y), UD5.4 (1Y), UD7.7 (A5), UE7.7 (A5)
/HC2000_5/VMA6: UC4.4 (1Y), UD5.7 (2Y), UD7.6 (A6), UE7.6 (A6)
/HC2000_5/VMA7: UC4.12 (4Y), UD5.12 (4Y), UD7.10 (A7), UE7.10 (A7)
A: UD5.13 (4B); also elsewhere on the board
A13M: UC4.2 (1A); also elsewhere on the board
A15: UC4.14 (4A); also elsewhere on the board
B: UD5.6 (2B); also elsewhere on the board
C: UD5.11 (3A); also elsewhere on the board
CASL: UD7.16 (~CAS), UE7.16 (~CAS); also elsewhere on the board
CPMP: UF3.3 (~Q1); also elsewhere on the board
CPMPL: UF3.2 (Q1); also elsewhere on the board
D: UD5.3 (1B); also elsewhere on the board
D4: UC7.17 (A4); also elsewhere on the board
D5: UC7.15 (A3); also elsewhere on the board
D6: UC7.11 (A1); also elsewhere on the board
D7: UC7.13 (A2); also elsewhere on the board
IG3: UG7.2 (1A); also elsewhere on the board
IG4: UG7.5 (2A); also elsewhere on the board
IG5: UG7.11 (3A); also elsewhere on the board
INH: UD5.15 (G), UG7.15 (G); also elsewhere on the board
INHL: UC4.15 (G), UC5.15 (G); also elsewhere on the board
MUX: UC4.1 (~A/B), UC5.1 (~A/B), UD5.1 (~A/B), UE2.6 (O), UG7.1 (~A/B); also elsewhere on the board
unnamed: C6.1, R36.1, UE2.4 (I0), UE2.5 (I1)
unnamed: UE3.4 (I0), UF3.15 (Q4)
unnamed: UE3.6 (O), UF3.9 (CLK)
OUT7EL: UE3.5 (I1); also elsewhere on the board
RASL: R36.2, UD7.5 (~RAS), UE7.5 (~RAS); also elsewhere on the board
RESETL: UF3.1 (CLR); also elsewhere on the board
VD0: UC7.16 (Y2), UD7.2 (I/O1); also elsewhere on the board
VD1: UC7.14 (Y3), UD7.3 (I/O2); also elsewhere on the board
VD2: UC7.12 (Y4), UD7.15 (I/O3); also elsewhere on the board
VD3: UC7.18 (Y1), UD7.17 (I/O4); also elsewhere on the board
VD4: UC7.3 (Y4), UE7.2 (I/O1); also elsewhere on the board
VD5: UC7.5 (Y3), UE7.3 (I/O2); also elsewhere on the board
VD6: UC7.9 (Y1), UE7.15 (I/O3); also elsewhere on the board
VD7: UC7.7 (Y2), UE7.17 (I/O4); also elsewhere on the board
WRAML: UC7.1 (G), UC7.19 (G), UD7.4 (~WE), UE7.4 (~WE); also elsewhere on the board
X3Y7: UD5.2 (1A); also elsewhere on the board
X5: UG7.10 (3B); also elsewhere on the board
X6: UG7.3 (1B); also elsewhere on the board
X7: UG7.6 (2B); also elsewhere on the board
X8: UG7.13 (4B); also elsewhere on the board
X9: UD5.10 (3B); also elsewhere on the board

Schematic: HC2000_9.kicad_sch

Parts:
R26, R42, R45: 330/-; 0204_7
R28, R40, R41: 220/1k; 0204_7
R37, R38: 1k; 0204_7
UA11: 74LS06; DIL14
UB12: 74LS153; DIL16
UC12: 74LS175; DIL16
UD11: 74LS14; DIL14
UE8: 8272 or D765AC-2; DIL40
UG11: 74LS08; DIL14

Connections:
CLK8272: UC12.9 (CLK), UE8.19 (CLK); also elsewhere on the board
CS8272: UE8.4 (NCS); also elsewhere on the board
D4: UE8.10 (D4); also elsewhere on the board
D5: UE8.11 (D5); also elsewhere on the board
D6: UE8.12 (D6); also elsewhere on the board
D7: UE8.13 (D7); also elsewhere on the board
DIR: UA11.8 (O); also elsewhere on the board
DWIN: UE8.22 (DW); also elsewhere on the board
FRDATA: UE8.23 (RDDATA); also elsewhere on the board
unnamed: UA11.3 (I), UC12.2 (Q1)
unnamed: UA11.5 (I), UC12.1 (CLR), UE8.25 (WE)
unnamed: UA11.9 (I), UB12.9 (2Y)
unnamed: UA11.11 (I), UG11.8 (O)
unnamed: UA11.13 (I), UE8.27 (HDSEL)
unnamed: UB12.6 (1C0), UC12.5 (D2), UC12.10 (Q3)
unnamed: UB12.5 (1C1), UC12.12 (D3), UC12.15 (Q4)
unnamed: UB12.4 (1C2), UC12.7 (Q2)
unnamed: UB12.7 (1Y), UC12.4 (D1)
unnamed: UB12.10 (2C0), UB12.11 (2C1), UB12.12 (2C2), UB12.13 (2C3), UE8.38 (LCT/DIR)
unnamed: UB12.14 (A), UE8.32 (PS0)
unnamed: UB12.2 (B), UE8.31 (PS1)
unnamed: UC12.13 (D4), UE8.30 (WRDATA)
unnamed: UD11.8 (O), UE8.34 (WP/TS)
unnamed: UD11.6 (O), UG11.4 (I0)
unnamed: UE8.33 (FLT/TRK00), UG11.6 (O)
unnamed: UE8.37 (FR/STP), UG11.10 (I1)
unnamed: R38.1, UE8.15 (NDACK)
unnamed: UE8.39 (NRW/SEEK), UG11.5 (I1), UG11.9 (I0)
unnamed: R37.1, UE8.35 (RDY)
PROT: R26.2, R28.1, UD11.9 (I); also elsewhere on the board
RD8272: UE8.2 (NRD); also elsewhere on the board
RES8272: UE8.1 (RST); also elsewhere on the board
SIDE: UA11.12 (O); also elsewhere on the board
STEP: UA11.10 (O); also elsewhere on the board
TC: UE8.16 (TC); also elsewhere on the board
TRACK0: R40.1, R45.2, UD11.5 (I); also elsewhere on the board
VCO: UE8.24 (VCO); also elsewhere on the board
WR8272: UE8.3 (NWR); also elsewhere on the board
WRCLK: UE8.21 (WRCLK); also elsewhere on the board
WRDATA: UA11.4 (O); also elsewhere on the board
WREN: UA11.6 (O); also elsewhere on the board

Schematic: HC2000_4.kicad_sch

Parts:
C5: 270p; C025-030X050
C11: 270p; C025-025X050
R19, R19B0: 470; 0204_7
UB1: 74LS74; DIL14
UB2: 74LS00; DIL14
UC2: 74LS27; DIL14
UC3: 74LS32; DIL14
UD1: 74LS08; DIL14
UE3: 74LS32; DIL14
UF4: 74LS74; DIL14
UH4: 74LS86; DIL14

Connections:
/HC2000_4/BLANKH: UB1.9 (Q), UC2.11 (I2), UD1.1 (I0)
/HC2000_4/HSYNCL: UB1.13 (CLR), UC3.3 (O), UD1.12 (I0), UH4.12 (I0)
BLANK: UD1.3 (O); also elsewhere on the board
BORD: UF4.5 (Q); also elsewhere on the board
HSYNC: UB1.3 (CLK), UB1.8 (~Q), UD1.13 (I1); also elsewhere on the board
IG0: UC2.9 (I0); also elsewhere on the board
IG1: UC2.10 (I1); also elsewhere on the board
IG2: UC2.5 (I2); also elsewhere on the board
IG4: UC2.4 (I1); also elsewhere on the board
IG5: UE3.9 (I0); also elsewhere on the board
IG6: UB2.5 (I1); also elsewhere on the board
IG7: UB2.4 (I0); also elsewhere on the board
IG8: UE3.10 (I1); also elsewhere on the board
INTL: R19.2; also elsewhere on the board
unnamed: UB1.2 (D), UB1.6 (~Q)
unnamed: UB1.12 (D), UC3.1 (I0), UC3.6 (O)
unnamed: UB2.6 (O), UB2.9 (I0)
unnamed: R19B0.1, UB2.8 (O)
unnamed: UB2.12 (I0), UC2.8 (O)
unnamed: R19.1, UB2.11 (O)
unnamed: UC2.3 (I0), UD1.2 (I1), UE3.8 (O)
unnamed: C11.1, R19B0.2, UF4.2 (D)
SHVL: UH4.11 (O); also elsewhere on the board
VSYNCL: UB2.13 (I1), UC2.6 (O), UH4.13 (I1); also elsewhere on the board
X4L: UF4.3 (CLK); also elsewhere on the board
X6: UB1.11 (CLK); also elsewhere on the board
X7: C5.2, UC3.2 (I1); also elsewhere on the board
X8: UC3.5 (I1); also elsewhere on the board
X10: UB2.10 (I1), UC3.4 (I0); also elsewhere on the board

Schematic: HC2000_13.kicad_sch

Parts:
C10: 270p; C025-025X050
Q2: 8MHz; HC18U-H
R39, R57: 560; 0204_7
R56: 220/1k; 0204_7
UD11: 74LS14; DIL14
UD12: 74LS161; DIL16
UE11: 74LS04; DIL14
UG11: 74LS08; DIL14
UG12: 74LS74; DIL14
UH11: 74LS93; DIL14
UH12: 74LS74; DIL14

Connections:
CLK8272: UD12.2 (CLK), UE11.9 (I), UH11.1 (CKB), UH11.12 (QA), UH12.3 (CLK); also elsewhere on the board
DWIN: UD12.6 (P4), UD12.11 (Q4); also elsewhere on the board
FRDATA: UG12.5 (Q); also elsewhere on the board
unnamed: UD11.4 (O), UH12.11 (CLK)
unnamed: UD12.9 (LD), UG12.6 (~Q), UH12.13 (CLR)
unnamed: Q2.1, R57.1, UE11.3 (I)
unnamed: C10.1, R57.2, UE11.4 (O)
unnamed: C10.2, R39.1, UE11.5 (I)
unnamed: Q2.2, R39.2, UE11.6 (O), UH11.14 (CKA)
unnamed: UE11.8 (O), UG12.3 (CLK)
unnamed: UG11.1 (I0), UH11.8 (QC)
unnamed: UG11.2 (I1), UH11.11 (QD)
unnamed: UG11.3 (O), UH12.1 (CLR)
unnamed: UG12.2 (D), UH12.9 (Q)
unnamed: UH12.2 (D), UH12.6 (~Q)
RDDATA: R56.2, UD11.3 (I); also elsewhere on the board
VCO: UD12.1 (~CL), UG12.1 (CLR); also elsewhere on the board
WRCLK: UH12.5 (Q); also elsewhere on the board

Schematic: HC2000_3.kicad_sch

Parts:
UC3: 74LS32; DIL14
UD4: 74LS157; DIL16
UE5: 74LS161; DIL16
UF2, UF5: 74LS161; DIL16
UG4: 74LS04; DIL14
UG5: 74LS161; DIL16
UH3: 74LS00; DIL14
UH7: 74LS161; DIL16

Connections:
3,5MHZ: UF2.7 (PE); also elsewhere on the board
17MHZ: UF2.2 (CLK); also elsewhere on the board
/HC2000_3/TC1: UE5.2 (CLK), UF2.15 (CO), UF5.2 (CLK), UG4.11 (I), UG5.2 (CLK), UH7.2 (CLK)
/HC2000_3/TCUC: UF5.7 (PE), UF5.10 (TE), UH3.10 (I1), UH7.15 (CO)
/HC2000_3/X4: UF2.11 (Q4), UG4.13 (I)
A: UD4.9 (3Y); also elsewhere on the board
B: UD4.4 (1Y); also elsewhere on the board
C: UD4.12 (4Y); also elsewhere on the board
D: UD4.7 (2Y); also elsewhere on the board
DOT: UC3.9 (I0), UD4.1 (~A/B); also elsewhere on the board
IG0: UD4.5 (2A), UF5.12 (Q3); also elsewhere on the board
IG1: UD4.2 (1A), UF5.11 (Q4); also elsewhere on the board
IG2: UD4.11 (3A), UE5.14 (Q1); also elsewhere on the board
IG3: UE5.13 (Q2); also elsewhere on the board
IG4: UE5.12 (Q3); also elsewhere on the board
IG5: UE5.11 (Q4); also elsewhere on the board
IG6: UD4.6 (2B), UD4.14 (4A), UG5.14 (Q1); also elsewhere on the board
IG7: UC3.10 (I1), UD4.3 (1B), UG5.13 (Q2); also elsewhere on the board
IG8: UG5.12 (Q3); also elsewhere on the board
unnamed: UE5.15 (CO), UG5.3 (P1), UG5.4 (P2), UG5.6 (P4), UG5.7 (PE), UG5.10 (TE)
unnamed: UE5.9 (LD), UG4.8 (O), UG5.9 (LD)
unnamed: UE5.4 (P2), UE5.7 (PE), UE5.10 (TE), UF5.15 (CO)
unnamed: UF2.14 (Q1), UG4.5 (I)
unnamed: UG4.9 (I), UG5.15 (CO)
unnamed: UH3.8 (O), UH7.9 (LD)
TC1L: UG4.10 (O); also elsewhere on the board
X1L: UG4.6 (O); also elsewhere on the board
X2: UF2.13 (Q2); also elsewhere on the board
X3Y7: UC3.8 (O); also elsewhere on the board
X4L: UG4.12 (O); also elsewhere on the board
X5: UH7.14 (Q1); also elsewhere on the board
X6: UH7.13 (Q2); also elsewhere on the board
X7: UH7.12 (Q3); also elsewhere on the board
X8: UH7.11 (Q4); also elsewhere on the board
X9: UF5.14 (Q1), UH3.9 (I0); also elsewhere on the board
X10: UF5.13 (Q2), UH7.3 (P1), UH7.4 (P2), UH7.5 (P3); also elsewhere on the board

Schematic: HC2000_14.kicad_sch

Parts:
CD1, CD6, CD9, CD11, CD13, CD15, CD16, CD17, CD19, CD20, CD21, CD22, CD24, CD25, CD26, CD27, CD30, CD31, CD32, CD33, CD35, CD36, CD37, CD39, CD40: u1; C025-024X044
CD2, CD4, CD7, CD8, CD10, CD14, CD28, CD29, CD34, CD38: -; C025-024X044
CD3, CD5, CD12, CD18, CD23: 100u; C025-024X044
CX0: 100u; C025-024X044
J1: VIDEO; DSUB-9_Female_Horizontal_P2.77x2.84mm_EdgePinOffset7.70mm_H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
J2: JOYSTICK; DSUB-9_Male_Horizontal_P2.77x2.84mm_EdgePinOffset7.70mm_Hou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
J3: MAB5SH
J4, J6: .; HC-POWER
J5: RS232 + RETEA; DSUB-9_Female_Horizontal_P2.77x2.84mm_EdgePinOffset7.70mm_H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
J7, J8: FDD-CON; 2X17
J9: .; 10X04MTA
J10: SDS-60J; SDS-60J-CUI_SDS-60J
JP2: -; JP1
SW1: RESET_SW
UA1: 74LS244; DIL20
Z1: HCBUS; HC_Bus_Edge_Connector

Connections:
+5V: J7.5, J7.6, J8.5, J8.6
+12V: J4.4, J6.4, J7.1, J7.2, J8.1, J8.2, J10.4; also elsewhere on the board
-12V: J4.3, J6.3, J10.2; also elsewhere on the board
A15: Z1.A1 (A15); also elsewhere on the board
B25: Z1.B25 (~ROMCS); also elsewhere on the board
BUSAKL: Z1.B26 (~BUSACK); also elsewhere on the board
BUSRQL: Z1.B19 (~BUSRQ); also elsewhere on the board
CASL: Z1.B8 (CLK); also elsewhere on the board
CPM: Z1.B4 (+9V); also elsewhere on the board
CTS: J5.1; also elsewhere on the board
D4: Z1.A12 (D4); also elsewhere on the board
D5: Z1.A10 (D5); also elsewhere on the board
D6: Z1.A9 (D6); also elsewhere on the board
D7: Z1.A3 (D7); also elsewhere on the board
DIR: J7.18, J8.18; also elsewhere on the board
DS0: J7.10, J7.14, J8.12, J8.16; also elsewhere on the board
DS1: J7.12, J7.16, J8.10, J8.14; also elsewhere on the board
DTR: J5.2; also elsewhere on the board
EAR: J3.3; also elsewhere on the board
HALTL: Z1.A15 (~HALT); also elsewhere on the board
HSYNC: UA1.2 (A1); also elsewhere on the board
INTL: Z1.A13 (~INT); also elsewhere on the board
IORQE: Z1.B13 (~IORQGE); also elsewhere on the board
IORQL: Z1.A17 (~IORQ); also elsewhere on the board
M1L: Z1.A24 (~M1); also elsewhere on the board
MBRIGHT: UA1.17 (A4); also elsewhere on the board
MIC: J3.1; also elsewhere on the board
NET: J5.5; also elsewhere on the board
NMIL: Z1.A14 (~NMI); also elsewhere on the board
unnamed: J3.5, JP2.2
unnamed: J1.8, UA1.18 (Y1)
unnamed: J1.4, UA1.16 (Y2)
unnamed: J1.5, UA1.14 (Y3)
unnamed: J1.9, UA1.12 (Y4)
unnamed: J1.3, UA1.7 (Y2)
unnamed: J1.1, UA1.5 (Y3)
unnamed: J1.6, UA1.3 (Y4)
PROT: J7.28, J8.28; also elsewhere on the board
RDDATA: J7.30, J8.30; also elsewhere on the board
RDL: Z1.A18 (~RD); also elsewhere on the board
REFSHL: Z1.A25 (~RFSH); also elsewhere on the board
RESETL: SW1.2, Z1.B20 (~RESET); also elsewhere on the board
RXD: J5.3; also elsewhere on the board
SHVL: UA1.15 (A3); also elsewhere on the board
SIDE: J7.32, J8.32; also elsewhere on the board
STEP: J7.20, J8.20; also elsewhere on the board
TA11: J2.7; also elsewhere on the board
TA12: J2.8; also elsewhere on the board
TD0: J2.4; also elsewhere on the board
TD1: J2.3; also elsewhere on the board
TD2: J2.9; also elsewhere on the board
TD3: J2.2; also elsewhere on the board
TD4: J2.1; also elsewhere on the board
TRACK0: J7.26, J8.26; also elsewhere on the board
TXD: J5.4; also elsewhere on the board
VIDEO: J1.7, J9.1, J9.4; also elsewhere on the board
VSYNCL: UA1.8 (A4); also elsewhere on the board
WAITL: Z1.A21 (~WAIT); also elsewhere on the board
WRDATA: J7.22, J8.22; also elsewhere on the board
WREN: J7.24, J8.24; also elsewhere on the board
WRL: Z1.A19 (~WR); also elsewhere on the board

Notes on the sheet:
CAS-DIN

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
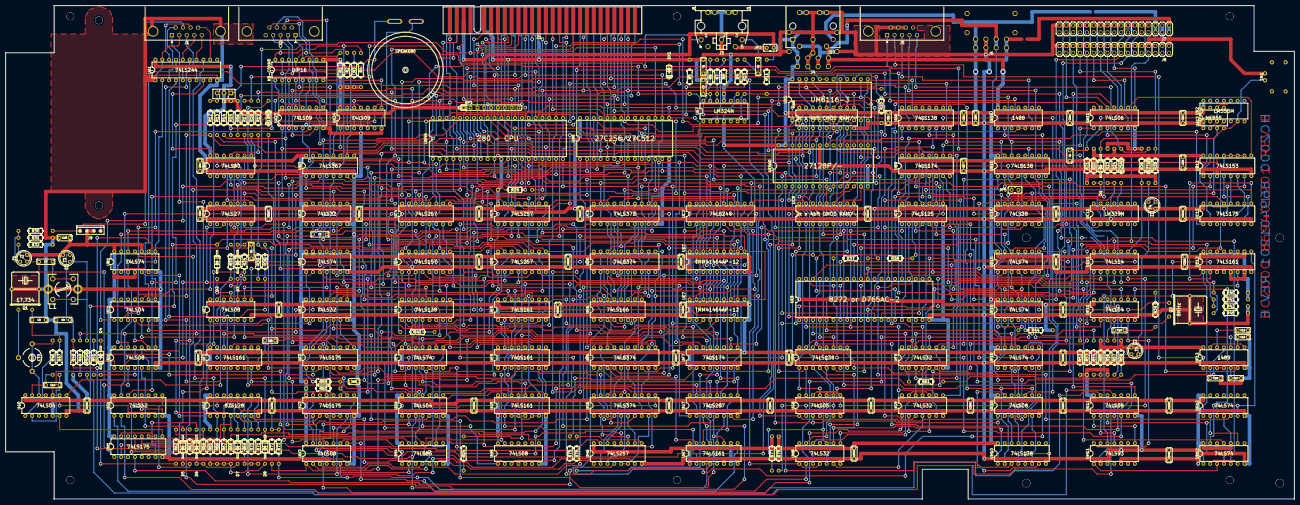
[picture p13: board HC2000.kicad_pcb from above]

Board: 2 copper layers, 478.0 x 183.0 mm, 259 parts (0 on the bottom side), 374 nets.

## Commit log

2023-04-25 Updated ICs values and positions
    [HC2000-B_Cu.gbl, HC2000-B_Mask.gbs, HC2000-B_Paste.gbp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]
2023-05-16 Fix errors (IC & unnoticed cut for 1 EPROM)
    [BOM.xlsx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]
2023-05-16 Rebuilt BOM
    [HC2000.csv]
2023-05-17 First Rev PCB Fixes
2023-05-24 Case parts
